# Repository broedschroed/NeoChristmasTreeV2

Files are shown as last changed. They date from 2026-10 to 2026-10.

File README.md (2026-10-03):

# NeoChristmasTree V2

An ESP32-powered Christmas tree ornament built from two interlocking,
fir-tree-shaped PCBs, lit by 66 individually addressable WS2812 LEDs and
controlled by an IR remote or a browser-based pattern editor.

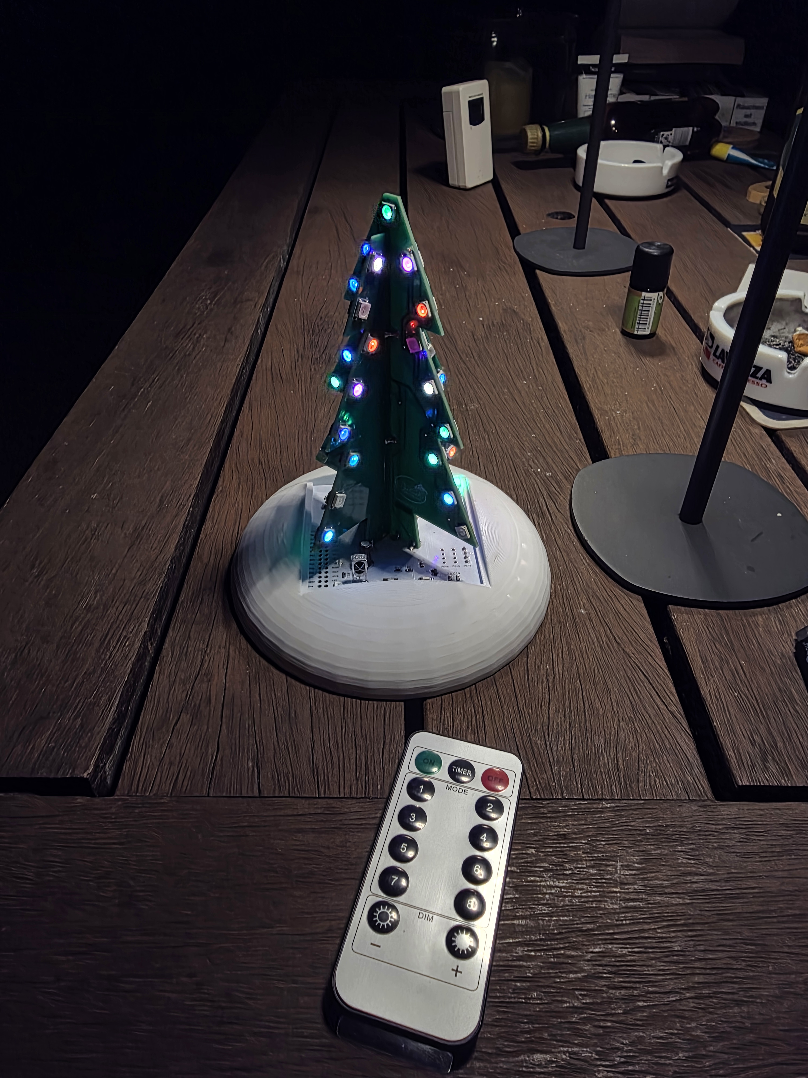
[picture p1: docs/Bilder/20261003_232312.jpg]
NeoChristmasTree lit up, with remote


## Highlights

- **66x WS2812 LEDs** across 4 wings (2 PCBs plugged together at a right
  angle, front and back of each), plus 2 tip LEDs at the very top.
- **IR remote control** — direct pattern selection, brightness, on/off, and
  a learnable sleep timer (30 minutes to 4 hours, set by repeatedly pressing
  the Timer button; the tree shows the corresponding "level" of its wings as
  live feedback).
- **Remote-learning mode** — any compatible IR remote's 13 buttons can be
  taught to the tree, with LED feedback on the tree itself during learning.
- **Browser-based pattern editor** — while powered via USB, the tree opens
  a local WiFi access point with a web UI (served from LittleFS) to create,
  edit, preview, and transfer lighting patterns between two trees.
- **Automatic brightness** — an onboard light sensor (LDR) adjusts LED
  brightness to the ambient light, capped by the brightness set via remote.
- **Proper power management** — on battery, switching off fully cuts power
  via a FET-driven double-click of the physical power button; on USB, the
  regulator stays active and only the LEDs go dark.

## Hardware

- ESP32 (NeoPixel data on pin 16)
- VS1838B IR receiver
- LDR for ambient-light sensing
- FET power switch to emulate a double-click power-off on battery
- Two interlocking fir-tree-shaped PCBs ("Tannenfluegellaengs" and
  "Tannenfluegelquer"), each carrying 32 of the 66 LEDs
- Main control board ("TannenbasisV4") carrying the ESP32, IR receiver, LDR
  and power management; KiCad sources for all three boards under
  `docs/Leiterplatten/`
- 3D-printed base housing; STL files under `docs/Gehäuse/`

## Repository layout

- `*.ino` / `*.h` — firmware (Arduino/ESP32 sketch)
- `data/www/` — the pattern editor web UI, uploaded to the ESP32's LittleFS
  filesystem (Arduino IDE "ESP32 Sketch Data Upload" or equivalent)
- `docs/manual/` — user manual (PDF)
- `docs/system/` — system documentation (PDF; describes an earlier hardware
  revision, kept for reference)
- `docs/Leiterplatten/` — KiCad sources, gerbers, schematic and front/back
  PCB renders for the control board and the two wing PCBs
- `docs/Gehäuse/` — STL files for the 3D-printed base housing
- `docs/Bilder/` — photos and a short clip of the finished tree

## Building

Open `NeoChristmasTreeV2.ino` in the Arduino IDE (or arduino-cli) with the
ESP32 core installed, plus the libraries IRremote, Adafruit NeoPixel,
ArduinoJson, and ESPAsyncWebServer. Flash the sketch, then upload the
contents of `data/` to the ESP32's LittleFS filesystem (e.g. via the "ESP32
Sketch Data Upload" tool) to make the pattern editor available.

Hold the mode/learn switch while powering on to enter IR remote-learning
mode.

## License

Released under the [MIT License](LICENSE).

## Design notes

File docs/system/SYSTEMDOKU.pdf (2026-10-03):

# NeoChristmasTree

## Systembeschreibung und Entwicklungsdokumentation

✦ ✦ ✦

Hardware: ESP32-S3-WROOM-1 · IP5306 · WS2812B Platine: TannenbasisV4 (KiCAD 10.0, 2-lagig) Software: Arduino / ESP-IDF · LittleFS · AsyncWebServer Gehäuse: 3D-Druck PLA (2-teiliger Einschub-Sockel)

────────────────────────────────────────────────────────────────────────────────

# 1 Projektübersicht

Der NeoChristmasTree ist ein ESP32-S3-basierter Weihnachtsbaum mit 66 adressierbaren WS2812B-LEDs, integriertem Akkubetrieb, Infrarot-Fernbedienung, WiFi-Webserver und automatischer Helligkeitsanpassung über einen Lichtsensor. Das Projekt richtet sich an Maker, die über grundlegende SMD-Löterfahrung verfügen, und zeigt einige unkonventionelle Lösungsansätze für typische Herausforderungen im Hobby-Bereich. Besondere Merkmale des Projekts:
- Integriertes Akkumanagement mit IP5306 (Laden und Boost in einem Chip) statt der üblichen zweiteiligen TP4056 + Boost-Converter-Lösung
- Eigens entwickeltes PCB-Footprint für den IP5306 mit extra großem GND-Thermal-Pad (3,65 × 8,55 mm) zum Löten ohne Heißluftstation
- USB-C-Stecker als Ladeeingang — Bestückung unter dem Kameramikroskop
- Webbasierter Pattern-Editor (LittleFS + AsyncWebServer) erreichbar über WiFi-Accesspoint
- Automatische LDR-Helligkeitsanpassung an das Umgebungslicht
- 2-teiliger 3D-Druck-Sockel mit Einschub-Mechanismus für die Platine

────────────────────────────────────────────────────────────────────────────────

# 2 Systemarchitektur

### 2.1 Blockdiagramm

Das folgende Diagramm zeigt den Energiepfad und die Datenflüsse des Systems:

┌──────────────┐ | USB-C (5 V) | ┌────────────────────────────────┐
│ LiPo-Akku | │◄────────────────►│ | IP5306 | │
│ | 1S / 3,7V │ | │ Laderegler + 5V-Boost-Wandler │
└──────────────┘ | │ Ladestandsanzeige (4 LEDs) | │
└──────────┬─────────────────────┘ │ 5 V Bus
┌────────────────────┼──────────────────────┐
│ | │ | │
┌──────▼──────┐ | ┌────────▼────────┐
┌────────▼───────┐
│ AMS1117-33 │ | │ 66× WS2812B | │ | │ BSS123 FET
│
│ 3,3V-Regler│ | │ LED-Strip | │ | │ Power-Switch
│
└──────┬──────┘ └─────────────────┘ └───────────────┘
│ 3,3 V

┌──────▼──────────────────────────────────────────────────┐
│ | ESP32-S3-WROOM-1
│
│
│
│ IO16 → WS2812-Daten IO38 ← IR-Empfänger VS1838B │
│ IO02 ← LDR (Analogein.) IO10 ← Taste mode/learn
│
│ IO04 ← Taste On/Off IO05 ← USB-Spannungsmessung │
│ IO15 → FET-Steuerung IO21 → Status-LED
│
│
│
│ WiFi-AP ──────────────► Webserver (192.168.4.1)
│
│ IR-Empfang ───────────► Pattern / Helligkeit / Power │

└──────────────────────────────────────────────────────────┘

### 2.2 Betriebsmodi

Modus | Stromversorgung | WiFi | Power-Off
Akkubetrieb | LiPo IP5306-Boost → → 5V | Aus (Stromsparen) | Vollständig (FET-Doppelklick)
USB-Betrieb | USB-C IP5306 → → 5V | AP aktiv | Nur LEDs aus, ESP32 aktiv

────────────────────────────────────────────────────────────────────────────────

# 3 Hardware-Beschreibung

### 3.1 Mikrocontroller — ESP32-S3-WROOM-1

Das Herzstück der Schaltung ist das ESP32-S3-WROOM-1-Modul von Espressif. Gegenüber dem älteren ESP32 bietet der S3 einen schnelleren Dual-Core-Xtensa-LX7-Prozessor (240 MHz), mehr SRAM (512 KB intern) sowie USB-OTG-Unterstützung. Für dieses Projekt entscheidend ist die reichhaltige Peripherie: ausreichend GPIOs für LEDs, IR, LDR und Taster sowie das integrierte WiFi für den Webserver.
Parameter | Wert
Prozessor | Dual-Core Xtensa LX7, 240 MHz
Flash | 4 MB (im Modul, genutzt für LittleFS-Patterns)
RAM | 512 KB intern + 8 MB PSRAM (im Modul)
WiFi | 802.11 b/g/n, 2,4 GHz
Betriebsspannung | 3,3 V
Versorgung | AMS1117-3.3 (aus 5V-Bus des IP5306)

Das Modul enthält bereits alle notwendigen Beschaltungen (Quarz, Filter, Antenne). Auf der Platine sind lediglich die Abblockkondensatoren und die GPIO-Beschaltung nötig.

### 3.2 Akkumanagement — IP5306 vs. TP4056 + Boost

Die Wahl des Akkumanagement-ICs ist eine der zentralen Designentscheidungen dieses Projekts. In vielen Maker-Projekten wird die Kombination aus TP4056 (Ladecontroller) und einem separaten Boost-Converter (z. B. MT3608 oder SY7208) verwendet. Diese Lösung hat einige Nachteile, die der IP5306 in einem einzigen Chip behebt.

Warum nicht TP4056 + Boost? Die klassische Kombination benötigt zwei ICs mit je eigenem Induktor, eigener Beschaltung und eigenem Wirkungsgrad-Verlust. Der Ladestrom des TP4056 ist auf 1A begrenzt. Die Gesamteffizienz leidet durch die zwei Wandlerstufen — besonders bei niedrigem Akkustand.

Eigenschaft | TP4056 + MT3608 | IP5306 (dieses Projekt)
Integration | 2 ICs + 2 Induktoren | 1 IC + 1 Induktor
Max. Ladestrom | 1,0 A | 2,1 A (einstellbar)
Boost-Ausgangsstrom | bis ~2 A (MT3608) | bis 2,4 A
Boost-Effizienz | ~80–87 % | ~88–93 %
Power-Button-Logik | Extern nötig | Integriert (Doppelklick-Erkennung)
Ladestandsanzeige | Extern (keine oder 1 LED) | 4 LEDs direkt angesteuert
Platzbedarf | Groß (2 Footprints) | SOP-8 (8 × 5 mm)
Preis (ca.) | ~1,50 € (2 ICs) | ~0,80 € (1 IC)

Der IP5306 enthält einen synchronen Boost-Wandler mit integrierter Schottky-Diode und einem eigenen Laderegler. Besonders wertvoll für dieses Projekt: Der Chip erkennt Einfach- und Doppelklick auf den Power-Button in Hardware — genau die Logik, die für das Abschalten im Akkubetrieb benötigt wird.

Power-Button-Trick: Im Akkubetrieb schaltet ein Doppelklick auf den Power-Button den IP5306 vollständig ab. Der ESP32 simuliert diesen Doppelklick über einen BSS123-FET auf den Power-Pin
— so ist ein vollständiges Software-Power-Off möglich, ohne dass der Nutzer den Taster zweimal drücken muss.

Die vier Ladestand-LEDs (D1–D4, bestückt als SMD-LEDs 1210) zeigen in 25-%-Schritten den Akkustand an. Der IP5306 treibt diese LEDs direkt ohne externe Logik.

### 3.3 3,3V-Versorgung — AMS1117-3.3

Aus dem 5V-Bus des IP5306 erzeugt ein AMS1117-3.3 im SOT-223-Gehäuse die 3,3V für den ESP32-S3. Der AMS1117 ist ein LDO-Regler (Low-Dropout) mit bis zu 800 mA Ausgangsstrom — ausreichend für den ESP32 inklusive WiFi-Betrieb. Die Dropout-Spannung von ca. 1,2V ist bei einem 5V-Eingang unkritisch.
Parallel zum AMS1117 liegen Abblockkondensatoren (100nF keramisch + 100µF elektrolytisch) um Lastsprünge durch WiFi-Bursts und LED-Datenübertragung zu glätten.

### 3.4 Ladeeingang — USB-C-Stecker (Lötbesonderheit!)

Als Ladeeingang dient ein USB-C-Plug in einem eigens erstellten KiCAD-Footprint. USB-C bietet gegenüber Micro-USB den Vorteil der Steckerrichtungsfreiheit und höherer mechanischer Belastbarkeit — relevant für ein Gerät, das jede Weihnachtssaison aus der Schublade geholt und angeschlossen wird.

Löthinweis — Kameramikroskop empfohlen: Der USB-C-Connector hat Signalpins (CC1/CC2,
D+/D ) mit einer Breite von nur − | 0,3 mm und einem Pitch von 0,5 mm. Die GND- und VBUS-Pads
messen 0,6 mm. Ein Kameramikroskop (oder zumindest eine starke Lupe mit guter Beleuchtung) ist beim Bestücken und Verlöten dringend empfohlen, um Brücken zwischen den Pins zu
erkennen und zu beseitigen. Flussmittel-Gel und eine feine Lötspitze (max. 0,3 mm) sind Pflicht.

Mechanisch hält der Connector über vier Through-Hole-Lötösen (ovale Pads 1,0 × 1,8 mm und 1,0 × 2,1 mm), die auch von Hand gut verlötbar sind und die nötige Zugentlastung bieten.

### 3.5 Infrarot-Empfänger — VS1838B

Der VS1838B (Footprint: TSDP341xx) ist ein kompakter 38-kHz-IR-Empfänger im 3-Pin-Gehäuse. Er demoduliert das Trägersignal und liefert direkt das NEC-Protokoll-Signal an GPIO38 des ESP32. Die Library IRremote übernimmt die Dekodierung.
Besonderheit im Code: `strip.show()` wird nur aufgerufen, wenn `IrReceiver.isIdle()` true ist, um elektromagnetische Interferenzen zwischen WS2812-Datenleitung und IR-Empfänger zu vermeiden.

### 3.6 Umgebungslicht — LDR-Spannungsteiler

An GPIO2 liegt ein Spannungsteiler aus LDR (gegen VCC) und 100 kΩ (gegen GND). Bei
hellem Umgebungslicht sinkt der LDR-Widerstand höhere Spannung an GPIO2 → | →
höherer ADC-Wert hellere LEDs. Bei Dunkelheit kehrt sich das um. →
Der ESP32 liest den ADC-Wert alle 500 ms (konfigurierbar über `AUTO_BR_INTERVAL`) und mappt ihn linear auf den Helligkeitsbereich `[AUTO_BR_MIN, gBrightness]`. Dabei wirkt der per Fernbedienung eingestellte Wert `gBrightness` als Obergrenze — die automatische Helligkeit kann nie höher gehen als die manuelle Einstellung.
#define LDR_DARK | 200 | // ADC-Wert bei Dunkelheit → kalibrieren!

#define LDR_BRIGHT | 3500 | // ADC-Wert bei hellem Licht → kalibrieren!

#define AUTO_BR_MIN | | 3 // LED-Helligkeit bei Dunkelheit

#define AUTO_BR_MAX | 255 // LED-Helligkeit bei vollem Licht

#define AUTO_BR_INTERVAL | 500 // Messintervall in ms

### 3.7 Power-Management — BSS123 N-Kanal-FET

Ein BSS123 (SOT-23, N-Kanal-MOSFET, 170 mA, 100 V) verbindet GPIO15 des ESP32 mit dem Power-Button-Pin des IP5306. Durch gezielte Pulse auf GPIO15 simuliert der ESP32 den für den IP5306 erforderlichen Doppelklick zum Abschalten. Im USB-Betrieb wird dieser Pfad nicht genutzt (IP5306 kann über USB nicht vollständig abschalten).

────────────────────────────────────────────────────────────────────────────────

# 4 Platinen-Design (TannenbasisV4)

### 4.1 Übersicht

Parameter | Wert
Design-Tool | KiCAD 10.0
Lagen | 2 (F.Cu, B.Cu)
Abmessungen | ca. 80 × 60 mm (Schätzwert aus Bauteilkoordinaten)
Oberfläche | HASL oder ENIG empfohlen
Bestückung | Überwiegend SMD 0805, wenige THT-Bauteile

### 4.2 IP5306 — Das besondere Lötpad

Der IP5306 im SOP-8-Gehäuse hat acht Standard-Gullwing-Pads (2,85 × 0,7 mm) und ein thermisches Exposed-Pad (Pad 9, GND) auf der Unterseite. Dieses Thermal-Pad ist für die Wärmeableitung essenziell — und genau hier liegt die konstruktive Besonderheit dieses Designs.

Lötpad-Größe im Vergleich: Das Thermal-Pad des IP5306 ist im Standard-Datenblatt mit ca. 3,3 × 3,3 mm angegeben. Im Footprint dieses Projekts wurde ein kombiniertes Pad von 3,65 × 8,55 mm definiert (inklusive Lötbrücken-Flächen). Zusätzlich gibt es drei Thermal-Via-Löcher ( 0,5 ∅ mm) auf beiden Seiten des Chips, die das Pad für einen Standardlötkolben zugänglich machen.

Das Ergebnis: Wer keinen Heißluftlöter besitzt, kann den IP5306 mit einem 100-Watt-Lötkolben und ausreichend Flussmittel von der Seite über die Thermal-Vias verlöten. Die Vias leiten Wärme und Lot unter den Chip.

### 4.3 Schaltplan und Layout

Die folgenden Dokumente liegen dem Projekt bei:
- `docs/schematic.pdf` — vollständiger Schaltplan (exportiert aus KiCAD)
- `docs/pcb_front.pdf` — PCB-Vorderseite (F.Cu + Silkscreen + Outline)
- `docs/pcb_back.pdf` — PCB-Rückseite (B.Cu + Silkscreen + Outline)
- `TannenbasisV4-produce/` — fertige Gerber-Dateien für die Platinenfertigung Die Gerber-Dateien sind direkt bei Standard-PCB-Fertigern (z. B. JLCPCB, PCBWay) bestellbar.

────────────────────────────────────────────────────────────────────────────────

# 5 3D-Druck-Sockel

### 5.1 Konzept

Der Sockel ist als zweiteiliger Einschub konstruiert. Die Platine wird in den Hauptkörper eingeschoben und durch ein Endstück gesichert — keine Schrauben, kein Kleber. Das ermöglicht einfachen Zugang zur Platine für Wartung oder Umprogrammierung.

Datei | Beschreibung
`XmasTree-Base3-2-main.stl` | Hauptkörper mit Einschubführung für die Platine
`XmasTree-Base3-2-end.stl` | Abschlusskappe, sichert die Platine im Sockel

### 5.2 Druckempfehlungen

- Material: PLA (ausreichend für Innenbereich)
- Schichthöhe: 0,2 mm (Standardqualität)
- Infill: 20 % (Gyroid oder Grid)
- Supports: nicht erforderlich (Teile sind support-frei konstruiert)
- Perimeter: 3 Wände für ausreichende Stabilität der Einschubführung

────────────────────────────────────────────────────────────────────────────────

# 6 Software-Architektur

### 6.1 Übersicht der Module

Der Quellcode ist in mehrere `.ino`-Dateien aufgeteilt, die die Arduino-IDE gemeinsam kompiliert:
Datei | Funktion
`NeoChristmasTreeV2.ino` | Hauptdatei: Setup, Loop, Auto-Brightness, Power-Off-Logik
`pattering.ino` | Pattern-Renderer: liest aus PatternEngine, setzt LEDs
`IRhandling.ino` | IR-Empfang, IR-Lernmodus (12 Codes × 3-fache Bestätigung)
`filesystem.ino` | LittleFS: Pattern-Index laden, Pattern-JSON lesen/schreiben
`webserver.ino` | WiFi-AP + AsyncWebServer + REST-API für den Pattern-Editor
`myPrefHandling.ino` | NVS-Preferences: IR-Codes, Pattern-ID,

| Helligkeit persistent
`serialprintf.ino` | sprintf-Wrapper für komfortables Serial-Debugging
`PatternEngine.h` | Datenstruktur für geladene Patterns (Frames, Farben, Timing)
`AllPattern.h` | Definitionen eingebauter Fallback-Patterns
`IRcodes.h` | Default-IR-Codes (Golden Power Ningbo Fernbedienung)

### 6.2 Pattern-System (LittleFS + JSON)

Lichtmuster werden als JSON-Dateien im LittleFS-Dateisystem des ESP32-Flash gespeichert. Ein zentraler Index (`/patterns/_index.json`) listet alle verfügbaren Patterns mit ID und Anzeigename.

// Verzeichnisstruktur im Flash:
/patterns/
_index.json | ← Liste aller Patterns
[{"id":"rainbow","name":"Regenbogen"}, ...]
rainbow.json | ← Pattern-Daten (Frames, Farben, Timing)
snowfall.json
/www/
index.html | ← Pattern-Editor (Single-Page-App)

Das aktive Pattern wird über eine String-ID (z. B. `"rainbow"`) referenziert — nicht über einen Integer-Index. Das macht Patterns unabhängig von ihrer Reihenfolge und ermöglicht das Hinzufügen/Entfernen ohne Neukompilierung der Firmware.

### 6.3 WiFi-Accesspoint und Web-Editor

Im USB-Betrieb öffnet der ESP32 automatisch einen WiFi-Accesspoint (`SSID: ChristmasTree`, kein Passwort). Der AsyncWebServer liefert die Single-Page-App (HTML/JavaScript) und stellt folgende REST-Endpunkte bereit:
Endpunkt | Methode | Funktion
`/` | GET | Liefert index.html (Pattern-Editor-UI)

`/api/patterns` | GET | Gibt _index.json zurück (Patternliste)
`/api/pattern?id=X` | GET | Gibt Pattern-JSON für ID X zurück
`/api/pattern` | POST | Speichert Pattern-JSON (id im Body)
`/api/activate` | POST | Aktiviert Pattern direkt (ohne Speichern)
`/api/brightness` | POST | Setzt Helligkeit live

### 6.4 IR-Fernbedienung

Der IR-Empfänger wird über die IRremote-Library ausgelesen. Zwölf IR-Codes sind konfigurierbar (Patterns 1–8, OFF, ON, Dunkler, Heller) und werden im NVS-Flash gespeichert. Der Lernmodus (Taste `mode/learn` beim Einschalten gehalten) erfasst neue Codes mit dreifacher Bestätigung, um instabile China-Fernbedienungen zu tolerieren.

### 6.5 Automatische Helligkeit (LDR)

Die Auto-Brightness-Funktion liest den LDR-Wert alle `AUTO_BR_INTERVAL` Millisekunden und mappt ihn über `constrain()` und `map()` auf den Helligkeitsbereich:

void updateAutoBrightness() {
if (millis() - gLastLdrCheck < AUTO_BR_INTERVAL) return; gLastLdrCheck = millis();
int raw = analogRead(ROOMLIGHT);
int clamped = constrain(raw, LDR_DARK, LDR_BRIGHT);
int autoBr = map(clamped, LDR_DARK, LDR_BRIGHT, AUTO_BR_MIN, AUTO_BR_MAX);
autoBr | = constrain(autoBr, AUTO_BR_MIN, gBrightness); // IR-Wert als
Deckel
strip.setBrightness(autoBr);
}

### 6.6 Power-Management im Code

Die Firmware unterscheidet USB- und Akkubetrieb anhand des analogen Spannungswerts an `USB5VSENSE` (GPIO5). Liegt dieser unter 1000 (ADC-Rohwert), wird Akkubetrieb angenommen:
- USB: WiFi-AP starten, echter Power-Off nicht möglich `"offpattern"` anzeigen →
- Akku: WiFi aus, bei Ausschalt-Befehl FET-Doppelklick ausführen (`powerOff()`)

────────────────────────────────────────────────────────────────────────────────

# 7 Stückliste (BOM)

Automatisch extrahiert aus `TannenbasisV4.kicad_sch` (KiCAD 10.0). Alle SMD-Widerstände und -Kondensatoren sind im Format 0805 ausgeführt (handlöttauglich). Elektrolytkondensatoren sind bedrahtet (Radial).
Stk. | Referenz(en) | Wert / Typ | Footprint
3 | C1, C2, C13 | 10µF | C_0805_2012Metric
1 | C14 | 100n | C_0805_2012Metric
2 | C3, C8 | 100nF | C_0805_2012Metric
2 | C4, C12 | 100µF | CP_Radial_D6.3mm_ P2.50mm
6 | C5, C6, C7, C9, C10, C11 | 22µF | C_1210_3225Metric_ Pad1.33x2.70mm
1 | D1 | 25% | LED_1210_3225Metr ic_Pad1.42x2.65mm
1 | D2 | 50% | LED_1210_3225Metr ic_Pad1.42x2.65mm
1 | D3 | 75% | LED_1210_3225Metr ic_Pad1.42x2.65mm
1 | D4 | 100% | LED_1210_3225Metr ic_Pad1.42x2.65mm
1 | D6 | LED | LED_1210_3225Metr ic_Pad1.42x2.65mm
1 | J1 | Battery | PinHeader_1x02_P2. 54mm_Vertical
2 | J10, J11 | LED2in | solderconnect-1
1 | J12 | USB_B_Micro | USB_Micro-B_Pins
2 | J13, J14 | mount | solderconnect-1

1 | J15 | I2Cb | PinHeader_1x04_P2. 54mm_Vertical
1 | J16 | I2Ca | PinHeader_1x04_P2. 54mm_Vertical
1 | J18 | LDR | PinHeader_1x02_P2. 54mm_Vertical
1 | J19 | Developer-IO | PinHeader_2x14_P2. 54mm_Vertical
2 | J2, J3 | LEDvdd | solderconnect-1
1 | J20 | I2Cc | PinHeader_1x04_P2. 54mm_Vertical
2 | J4, J5 | LEDvss | solderconnect-1
2 | J6, J7 | LEDdata | solderconnect-1
2 | J8, J9 | LED1out | solderconnect-1
1 | L1 | 1µH | MyPowerCoil
1 | P2 | USB-C-Plug-My | MyUSB-C
1 | Q1 | BSS123 | SOT-23
4 | R1, R2, R7, R8 | 1Ω | R_0805_2012Metric
3 | R10, R12, R14 | 100Ω | R_0805_2012Metric
1 | R11 | 220Ω | R_0805_2012Metric
1 | R17 | 1k | R_0805_2012Metric
2 | R3, R4 | 5k1 | R_0805_2012Metric
3 | R5, R16, R19 | 100k | R_0805_2012Metric
5 | R6, R9, R13, R15, R18 | 10k | R_0805_2012Metric
1 | SW1 | On/Off | SW_DIP_SPSTx01_Sli de_6.7x4.1mm_W8.6 1mm_P2.54mm_Low Profile
1 | SW2 | Reset | SW_DIP_SPSTx01_Sli de_6.7x4.1mm_W8.6 1mm_P2.54mm_Low Profile
1 | SW3 | mode/learn | SW_DIP_SPSTx01_Sli de_6.7x4.1mm_W8.6 1mm_P2.54mm_Low

| | | Profile
1 | SW4 | Boot/Flash | SW_DIP_SPSTx01_Sli de_6.7x4.1mm_W8.6 1mm_P2.54mm_Low Profile
1 | U1 | IP5306 | IP5306
1 | U2 | AMS1117-3.3 | SOT-223-3_TabPin2
1 | U3 | USBLC6-2SC6 | SOT-23-6
1 | U4 | VS1838B | Vishay_MOLD-3Pin
1 | U5 | ESP32-S3-WROOM-1 | ESP32-S3-WROOM-1

Gesamt: 69 Bauteile in 42 verschiedenen Typen.

────────────────────────────────────────────────────────────────────────────────

# 8 Inbetriebnahme

### 8.1 Firmware flashen

### 1. Arduino-IDE installieren und das ESP32-Boardpaket (Espressif, Version 2.0) ≥

einrichten.
2. Folgende Libraries installieren: IRremote, Adafruit NeoPixel, ESPAsyncWebServer, ArduinoJson, LittleFS.
3. Den ESP32 über den USB-Micro-B-Connector (J12) mit dem Computer verbinden.
4. Das Sketch `NeoChristmasTreeV2.ino` öffnen und auf den ESP32 hochladen.
5. Anschließend die LittleFS-Daten hochladen (Arduino-IDE Werkzeuge ESP32 → | →
LittleFS Data Upload). Enthält Pattern-JSON und den Web-Editor.

### 8.2 LDR kalibrieren

Die Rohwerte des LDR sind je nach verbautem Exemplar und Lichtbedingungen unterschiedlich. Kalibrierung:
1. Baum einschalten und Serial Monitor (115200 Baud) öffnen.
2. Den Baum in vollständiger Dunkelheit aufstellen `ROOMLIGHT=`-Wert notieren → | →
als `LDR_DARK` eintragen.

3. Den Baum bei normaler Raumbeleuchtung aufstellen Wert notieren als → | →
`LDR_BRIGHT` eintragen.
4. Firmware neu flashen.

### 8.3 IR-Fernbedienung anlernen

Falls eine andere als die mitgelieferte Fernbedienung (Golden Power Ningbo) verwendet werden soll: Taste `mode/learn` beim Einschalten gedrückt halten Lernmodus. 12 Tasten → nacheinander dreimal drücken. Details: siehe Bedienungsanleitung.

────────────────────────────────────────────────────────────────────────────────

NeoChristmasTree · TannenbasisV4 · broed · 2025

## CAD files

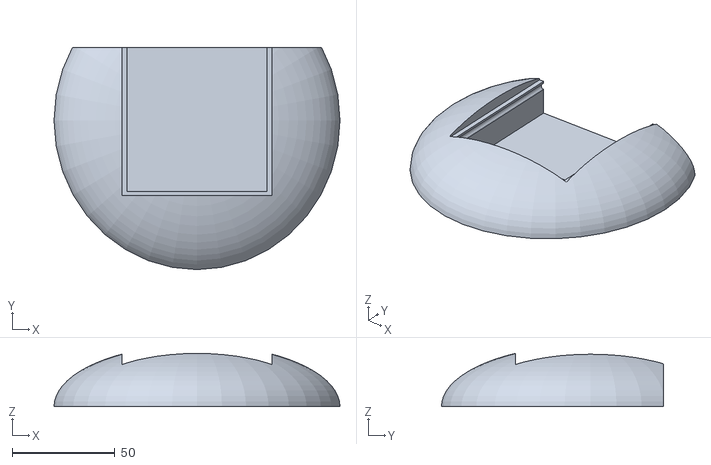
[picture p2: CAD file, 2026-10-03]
docs/Gehäuse/XmasTree-Base3-2-main.stl
139.0 x 108.0 x 25.9

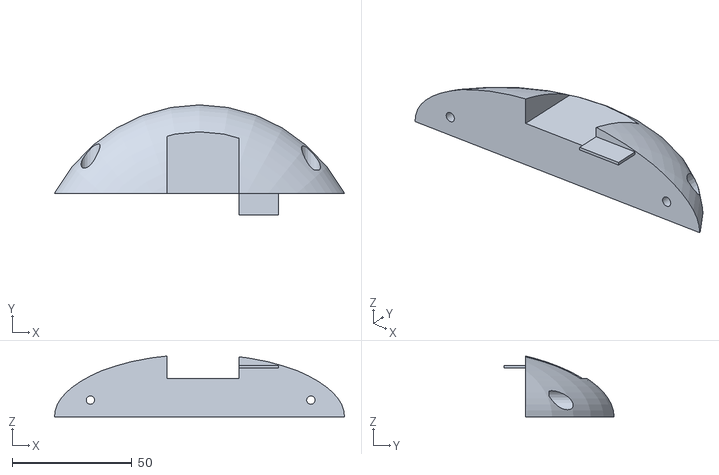
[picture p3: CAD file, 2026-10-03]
docs/Gehäuse/XmasTree-Base3-2-end.stl
121.0 x 46.0 x 25.4

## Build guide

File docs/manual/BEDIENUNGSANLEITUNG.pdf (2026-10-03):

# 🎄 NeoChristmasTree

## Bedienungsanleitung

✦ ✦ ✦

Dieser Weihnachtsbaum leuchtet in vielen verschiedenen Mustern und passt seine Helligkeit sogar selbst an das Raumlicht an. Diese Anleitung führt dich Schritt für Schritt vom Einschalten bis zur Anpassung der Lichtmuster — ganz ohne Vorkenntnisse.

────────────────────────────────────────────────────────────────────────

### 1 Die Tasten am Baum

Am Baum selbst gibt es zwei Tasten: die Taste On/Off zum Ein- und Ausschalten und die Taste mode/learn zum Wechseln der Lichtmuster. Außerdem passt der Baum seine Helligkeit automatisch dem Raumlicht an.
Einschalten
Die Taste On/Off einmal kurz drücken — der Baum startet und zeigt das zuletzt verwendete Muster.
Ausschalten
Die Taste On/Off erneut kurz drücken — der Baum geht aus.

Gut zu wissen: Das zuletzt verwendete Muster und die Helligkeit werden automatisch gespeichert. Beim nächsten Einschalten macht der Baum genau dort weiter, wo er aufgehört hat.

Muster wechseln
Die Taste mode/learn einmal kurz drücken — der Baum wechselt zum nächsten Lichtmuster. Einfach so oft drücken, bis das gewünschte Muster erscheint. Nach dem letzten Muster beginnt die Liste wieder von vorne.
Automatische Helligkeit
Im Baum ist ein kleiner Lichtsensor eingebaut. Er misst ständig, wie hell es im Raum ist, und passt die LED-Helligkeit automatisch an:

- Tagsüber oder bei eingeschaltetem Licht leuchtet der Baum heller.
- Abends oder bei gedimmtem Licht leuchtet der Baum sanfter.
Das passiert ganz von selbst — es ist nichts einzustellen. Die per Fernbedienung eingestellte Helligkeit wirkt dabei als Obergrenze: Heller als dieser Wert wird der Baum nie, auch wenn der Raum sehr hell ist.

────────────────────────────────────────────────────────────────────────

### 2 Die Fernbedienung

Mit der Fernbedienung lässt sich der Baum bequem aus dem Sessel steuern. Einfach auf den Baum richten und die gewünschte Taste drücken.
Muster direkt auswählen
Die Zifferntasten 1 bis 8 rufen die gespeicherten Lichtmuster direkt auf:
Taste | Muster
1 Zufällig wechselnde Farben 2 Klassisch-festliches Muster 3 Blinkende Lichter
4 Farben laufen den Baum hinauf 5 Farbige Linien
6 Farbige Seiten
7 Schneeeffekt in Weiß
8 Weißes Blinken

Tipp: Wenn eigene Muster über den WLAN-Editor gespeichert wurden (siehe Kapitel 4), können diese ebenfalls per Fernbedienung aufgerufen werden — die Tasten 1–8 zeigen dann die ersten acht Muster in der gespeicherten Liste.

Helligkeit einstellen
Taste | Funktion
dark | Baum etwas dunkler schalten
light | Baum etwas heller schalten

Einfach mehrfach drücken, bis die gewünschte Helligkeit erreicht ist. Diese Einstellung wird gespeichert und gilt als neuer Helligkeits-Höchstwert für die automatische Anpassung (siehe Kapitel 1).
Ein- und Ausschalten
Taste | Funktion
ON | Baum einschalten (zeigt das zuletzt aktive Muster)
OFF | Baum ausschalten

Was genau beim Ausschalten passiert, hängt davon ab, ob der Baum per USB oder per Akku betrieben wird — dazu mehr im nächsten Kapitel.

────────────────────────────────────────────────────────────────────────
Timer — automatisches Ausschalten
Die Taste Timer stellt eine automatische Abschaltzeit ein — praktisch, wenn der Baum abends von selbst ausgehen soll:

### 1. Timer einmal drücken: Die untersten LEDs des Baums leuchten kurz gold auf —

der Baum schaltet sich in 30 Minuten automatisch aus.

### 2. Timer erneut drücken, solange die LEDs noch leuchten: Eine weitere Ebene

leuchtet mit auf, die Abschaltzeit erhöht sich um weitere 30 Minuten.

### 3. So oft weiterdrücken, bis die gewünschte Zeit erreicht ist — jede Ebene entspricht

30 Minuten, bis hin zu 4 Stunden, wenn der ganze Baum leuchtet.

### 4. Ist die höchste Stufe (4 Stunden, ganzer Baum) erreicht, schaltet ein weiterer

Druck auf Timer die automatische Abschaltung wieder komplett aus — der Baum läuft sofort normal weiter.
Nach jedem Tastendruck läuft nach der kurzen Anzeige das zuvor aktive Lichtmuster ganz normal weiter; der Timer zählt im Hintergrund mit. Wird der Baum vor Ablauf der Zeit manuell aus- oder eingeschaltet (Taste On/Off am Baum, ON/OFF auf der Fernbedienung), wird der Timer automatisch verworfen. Beim Ablauf der Zeit schaltet sich der Baum genauso ab wie über die Taste OFF — im Akkubetrieb also vollständig, im USB-Betrieb gehen nur die LEDs aus (siehe nächstes Kapitel).

### 3 USB oder Akku — was ist der Unterschied?

Der Baum kann auf zwei Arten mit Strom versorgt werden: über ein USB-Kabel (z. B. an einem Netzteil oder Computer) oder über einen eingebauten Akku. Je nach Stromversorgung verhält er sich beim Ausschalten etwas anders.
Akkubetrieb
Im Akkubetrieb schaltet sich der Baum beim Ausschalten vollständig ab — auch die Elektronik im Inneren geht schlafen. Das spart Strom und schont den Akku.
- Einschalten: Taste On/Off am Baum einmal kurz drücken.
- Ausschalten: Taste On/Off am Baum einmal kurz drücken oder Taste OFF auf der Fernbedienung.
- Nach dem Ausschalten ist der Baum komplett stromlos. Er lässt sich nur wieder mit der Taste On/Off starten — die Fernbedienung funktioniert erst wieder, nachdem der Baum eingeschaltet wurde.

Hinweis: Wenn der Akku leer ist und der Baum gerade ausgeschaltet ist, schaltet er sich von selbst ab — damit sich der Akku nicht tiefentlädt.

USB-Betrieb
Über USB kann die Elektronik im Inneren nicht vollständig abgeschaltet werden — das ist technisch bedingt. Deshalb verhält sich der Baum hier etwas anders:
- Einschalten: USB-Kabel einstecken — der Baum startet automatisch.
- Ausschalten: Taste On/Off am Baum drücken oder Taste OFF auf der Fernbedienung → die LEDs gehen aus, aber die Elektronik bleibt aktiv.
- Wieder einschalten: Taste On/Off am Baum erneut drücken oder Taste ON auf der Fernbedienung.

Akku laden: Während der Baum per USB betrieben wird, lädt gleichzeitig der eingebaute Akku. Es empfiehlt sich daher, den Baum gelegentlich ans USB-Kabel zu hängen — besonders nach längerem Akkubetrieb.

Ein weiterer Vorteil des USB-Betriebs: Der Baum öffnet automatisch ein WLAN-Netzwerk, über das sich Lichtmuster am Tablet oder Notebook anpassen lassen (siehe nächstes Kapitel).

────────────────────────────────────────────────────────────────────────

### 4 Lichtmuster anpassen — der WLAN-Editor

Wenn der Baum per USB betrieben wird, öffnet er automatisch ein eigenes WLAN-Netzwerk. Darüber lassen sich die vorhandenen Lichtmuster am Tablet oder Notebook anpassen, speichern und sogar zwischen zwei Bäumen übertragen.

Voraussetzung: Der Baum muss per USB eingeschaltet sein. Im Akkubetrieb ist der WLAN-Editor nicht verfügbar.

Schritt 1 — Mit dem Baum verbinden
1. Am Tablet oder Notebook die WLAN-Einstellungen öffnen.

### 2. Das Netzwerk „ChristmasTree" auswählen und verbinden. Es wird kein Passwort

benötigt.
3. Einen Browser öffnen (z. B. Chrome, Firefox oder Safari).
4. In die Adresszeile oben 192.168.4.1 eintippen und die Eingabetaste drücken.
5. Der Muster-Editor erscheint im Browser.

Tipp: Falls nach dem Verbinden eine Meldung erscheint, dass „kein Internet verfügbar" ist — das ist normal und gewollt. Der Baum ist kein Internet-Router, sondern nur ein kleines lokales Netzwerk. Den Hinweis einfach wegklicken und den Browser öffnen.

Schritt 2 — Ein vorhandenes Muster verändern
Der einfachste Einstieg: Ein bestehendes Muster als Ausgangspunkt nehmen und anpassen.

### 1. Oben links in der Muster-Auswahlliste ein Muster auswählen — es wird sofort im

Editor angezeigt.

### 2. Im LED-Raster (Mitte) zeigt sich der Baum in einer vereinfachten Draufsicht. Jedes

Kästchen ist eine LED.
3. Rechts die gewünschte Farbe aus der Palette auswählen.
4. Im LED-Raster auf eine LED klicken — sie leuchtet in der gewählten Farbe.
5. Wenn das Muster gefällt: „ Aktivieren" ▶ | klicken, um es sofort am Baum zu sehen.
6. „ Speichern" ↑ | klicken, um das Muster dauerhaft zu sichern.

Überblick über alle Schaltflächen
Schaltfläche | Was sie macht
Muster-Auswahlliste | Gespeichertes Muster auswählen und im Editor laden
- Aktivieren | Das aktuell angezeigte Muster sofort am Baum anzeigen
↺ Original | Muster auf die Werkseinstellung zurücksetzen
Helligkeitsregler | LED-Helligkeit am Baum live verändern
↓ Import JSON | Ein Muster von einem anderen Baum einspielen
↑ Export JSON | Aktuelles Muster als Text kopieren, um es zu teilen
- Vorschau | Muster im Browser animiert abspielen (ohne den Baum)
↑ Speichern | Muster dauerhaft auf dem Baum speichern
PCB1 PCB2 → | Linke Baumhälfte spiegelgleich auf die rechte übertragen

Muster zwischen zwei Bäumen übertragen

Vom ersten Baum exportieren:
1. Das gewünschte Muster in der Auswahlliste auswählen.
2. „ Export JSON" ↑ | klicken — ein Textfeld mit dem Muster-Code öffnet sich.
3. „Kopieren" klicken.
Auf dem zweiten Baum einspielen:
1. Mit dem zweiten Baum verbinden (WLAN „ChristmasTree", Adresse 192.168.4.1).
2. „ Import JSON" ↓ | klicken — ein Eingabefenster öffnet sich.
3. Den kopierten Text einfügen (Strg+V).
4. „Importieren" klicken — das Muster erscheint im Editor.
5. „ Speichern" ↑ | klicken, um es dauerhaft zu sichern.

────────────────────────────────────────────────────────────────────────

### 5 Eine andere Fernbedienung anlernen

Der Baum merkt sich die Tasten einer bestimmten Fernbedienung. Soll eine andere Fernbedienung verwendet werden, müssen deren Tasten einmalig angelernt werden. Das dauert nur wenige Minuten.

Achtung: Dieser Vorgang löscht die bisherigen Fernbedienungstasten. Danach funktioniert nur noch die neu angelernte Fernbedienung.

Vorbereitung
- Den Baum ausschalten.
- Die neue Fernbedienung bereithalten.
- Die Taste mode/learn am Baum suchen — sie wird gleich beim Einschalten gedrückt. Lernmodus starten
1. Die Taste mode/learn am Baum gedrückt halten.
2. Gleichzeitig den Baum mit der Taste On/Off einschalten.

### 3. Die Taste mode/learn halten, bis die oberste LED rot leuchtet — das zeigt an, dass

der Baum bereit zum Lernen ist.
4. Taste mode/learn loslassen.
Tasten nacheinander anlernen
Der Baum erwartet nun genau 13 Tasten in einer festgelegten Reihenfolge. Für jede Taste gilt:
- Die gewünschte Taste auf der Fernbedienung dreimal hintereinander drücken — mit einer kurzen Pause zwischen den Drücken.
- Der Baum bestätigt jeden erfolgreich angelernten Code: Die Baumspitze blinkt zweimal auf.

Die Reihenfolge der 13 Tasten:
Schritt | Funktion
1 | Muster 1
2 | Muster 2
3 | Muster 3
4 | Muster 4
5 | Muster 5
6 | Muster 6
7 | Muster 7
8 | Muster 8
9 | Ausschalten (OFF)
10 | Einschalten (ON)
11 | Dunkler
12 | Heller
13 | Timer

Fortschrittsanzeige: Während des Lernens leuchtet auf allen vier Flügeln des Baums jeweils die Ebene 4 bis 6 in Farben auf und zeigt so an, wie weit der Lernvorgang fortgeschritten ist:
Farbe | Bedeutung
Grün | Tasten 1–3 gelernt
Cyan (Türkis) | Tasten 4–6 gelernt
Gelb | Tasten 7–9 gelernt
Magenta (Pink) | Tasten 10–12 gelernt
Weiß | Taste 13 (Timer) gelernt

Sobald alle 13 Tasten angelernt sind, speichert der Baum die Codes automatisch und startet normal. Die neue Fernbedienung ist sofort einsatzbereit.

Falls eine Taste nicht akzeptiert wird: Einfach dieselbe Taste erneut dreimal drücken. Manche Fernbedienungen senden beim ersten Druck einen anderen Code als bei den folgenden — der Baum verlangt daher dreimal denselben Code zur Sicherheit.

────────────────────────────────────────────────────────────────────────
🎄 | 🎄 NeoChristmasTree — viel Freude mit deinem leuchtenden Baum!

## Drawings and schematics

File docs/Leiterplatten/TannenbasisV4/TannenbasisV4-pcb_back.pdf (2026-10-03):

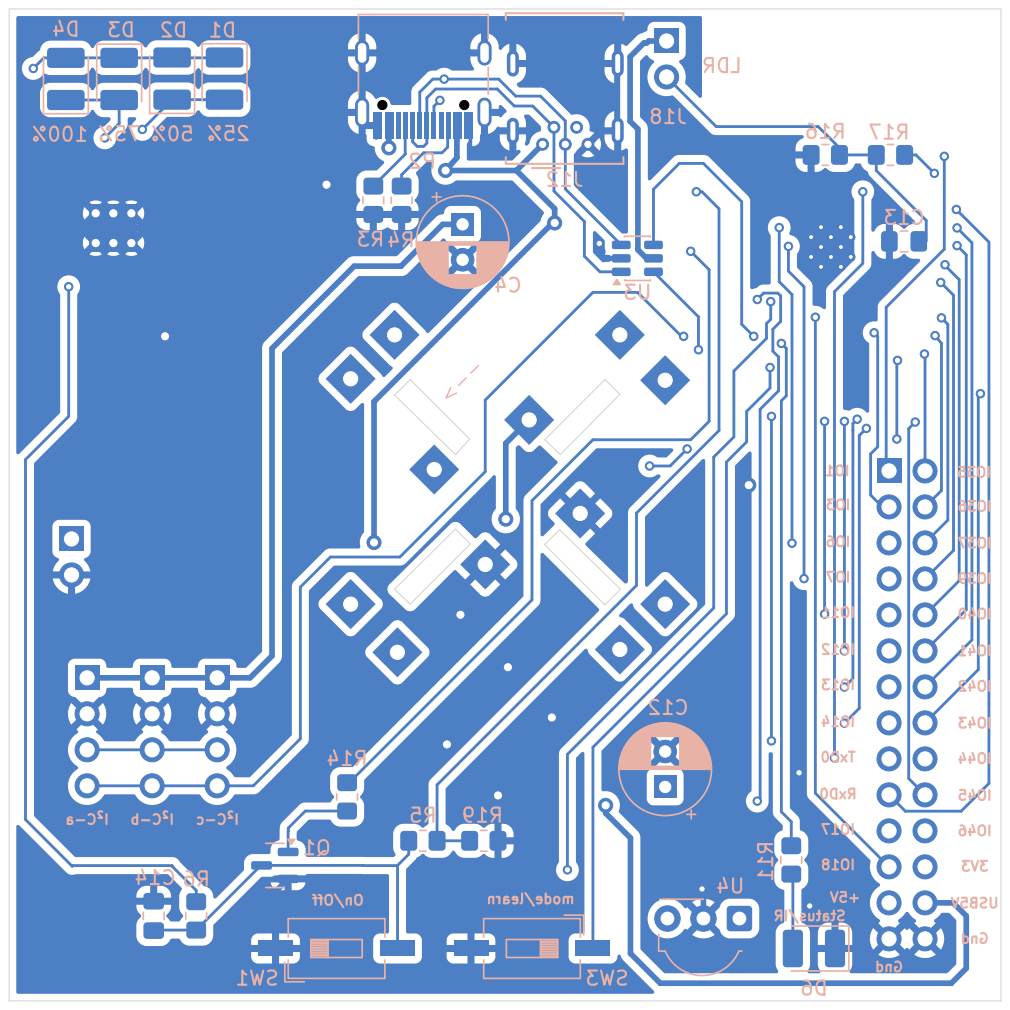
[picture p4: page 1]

I²C-a I²C-b I²C-c Status/IR

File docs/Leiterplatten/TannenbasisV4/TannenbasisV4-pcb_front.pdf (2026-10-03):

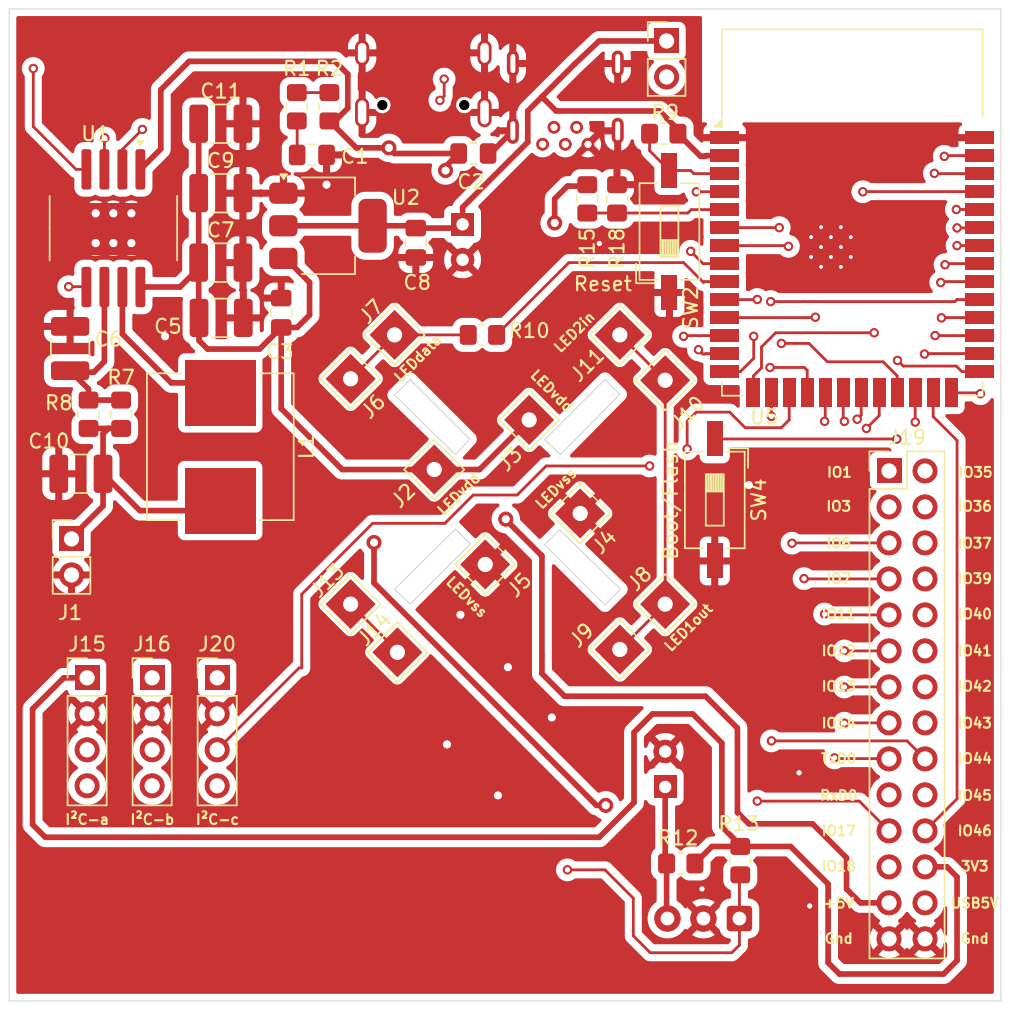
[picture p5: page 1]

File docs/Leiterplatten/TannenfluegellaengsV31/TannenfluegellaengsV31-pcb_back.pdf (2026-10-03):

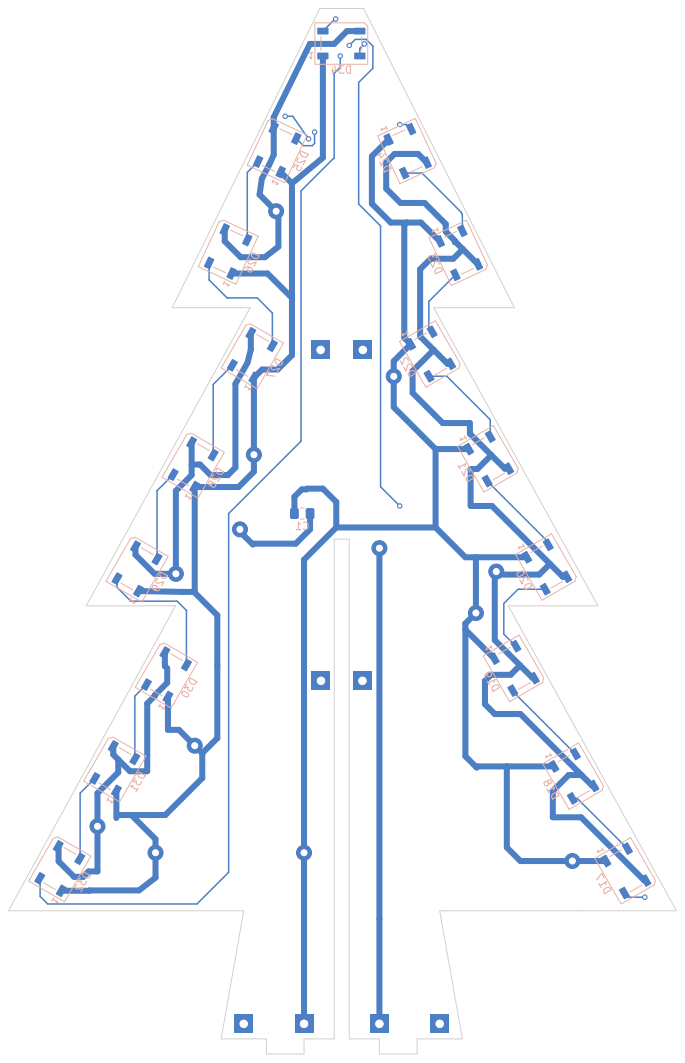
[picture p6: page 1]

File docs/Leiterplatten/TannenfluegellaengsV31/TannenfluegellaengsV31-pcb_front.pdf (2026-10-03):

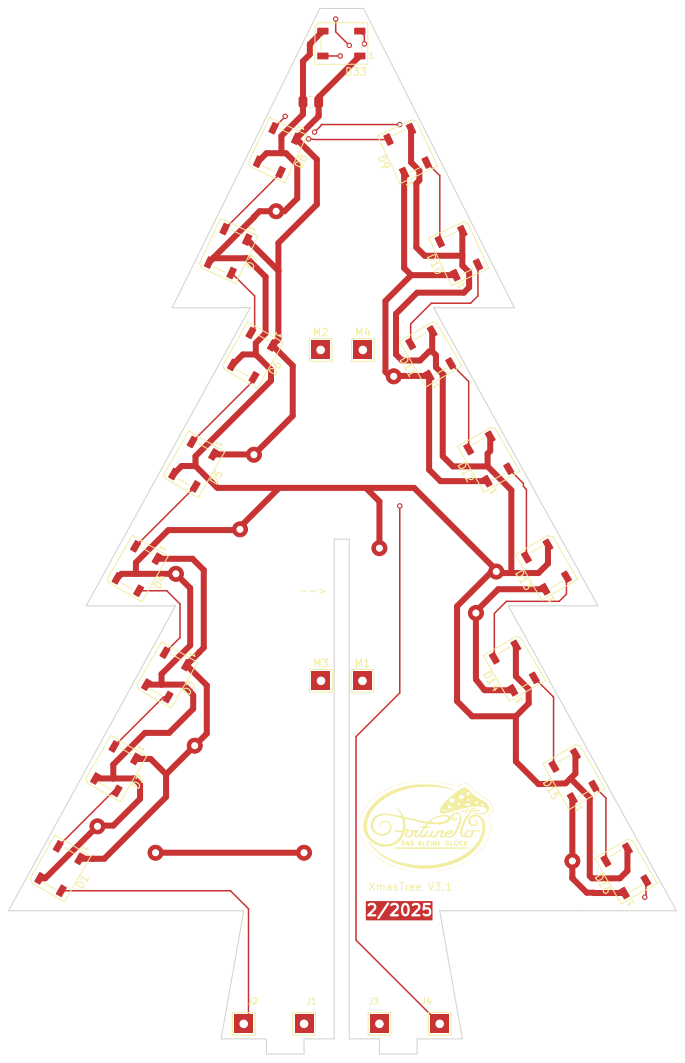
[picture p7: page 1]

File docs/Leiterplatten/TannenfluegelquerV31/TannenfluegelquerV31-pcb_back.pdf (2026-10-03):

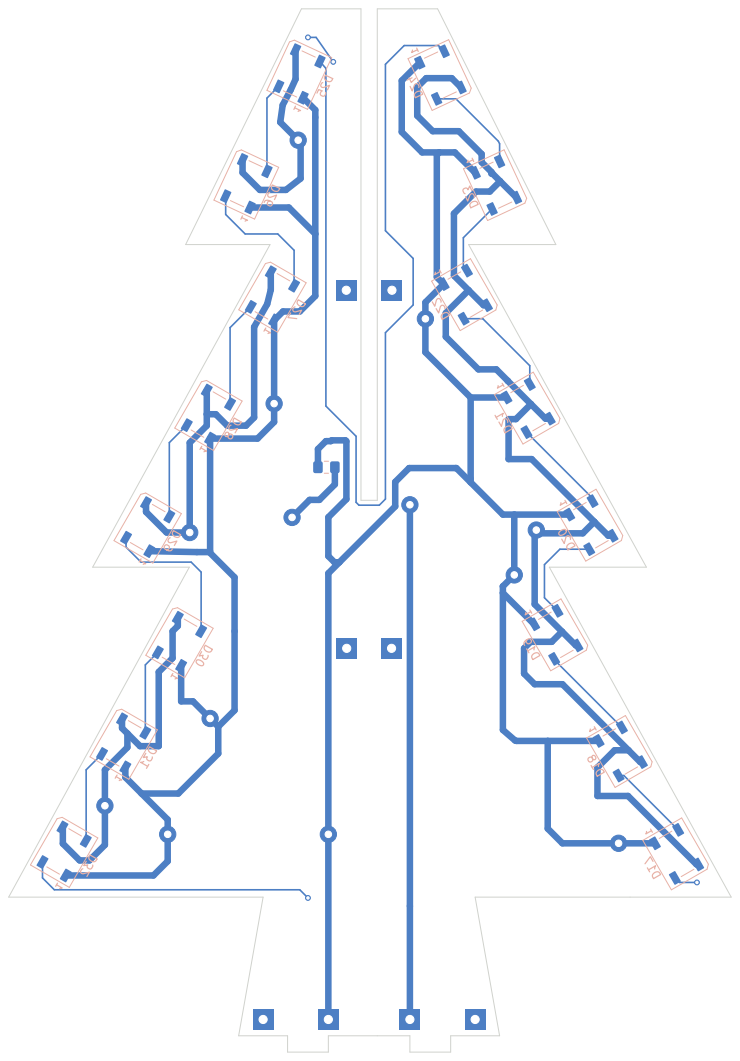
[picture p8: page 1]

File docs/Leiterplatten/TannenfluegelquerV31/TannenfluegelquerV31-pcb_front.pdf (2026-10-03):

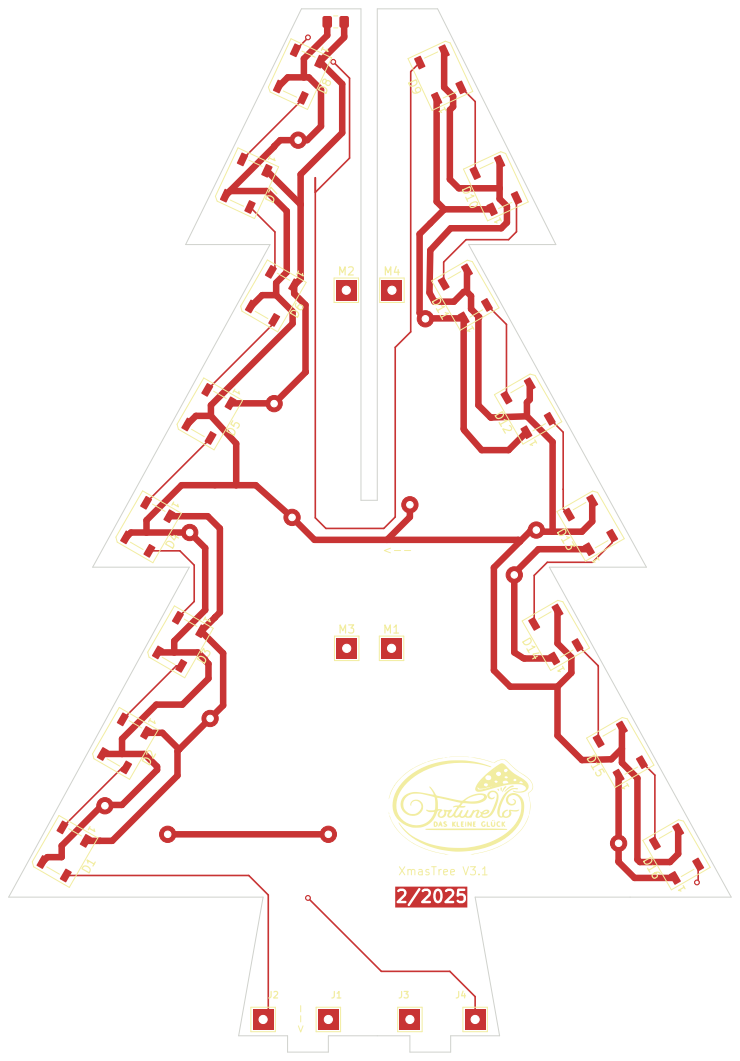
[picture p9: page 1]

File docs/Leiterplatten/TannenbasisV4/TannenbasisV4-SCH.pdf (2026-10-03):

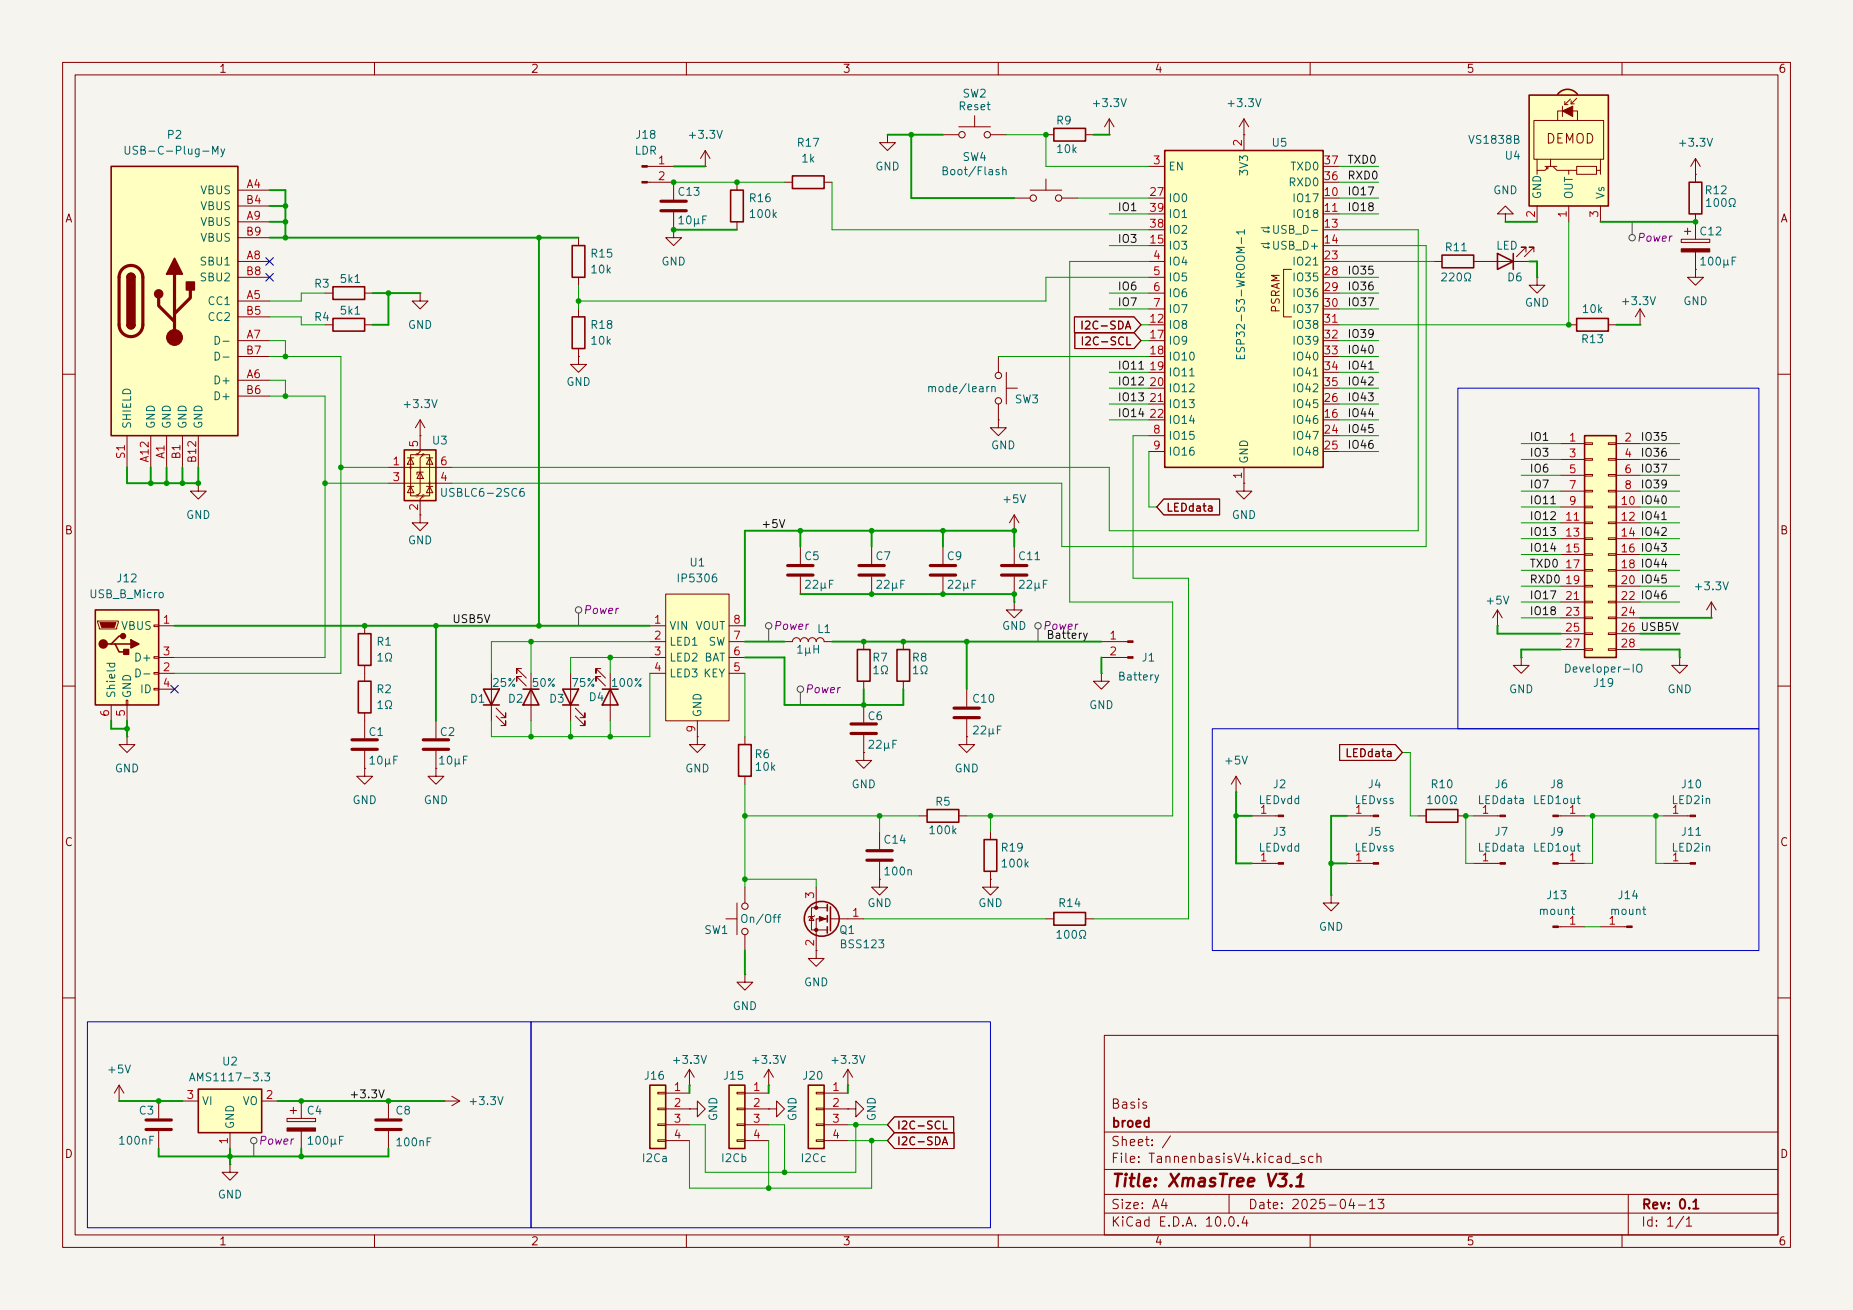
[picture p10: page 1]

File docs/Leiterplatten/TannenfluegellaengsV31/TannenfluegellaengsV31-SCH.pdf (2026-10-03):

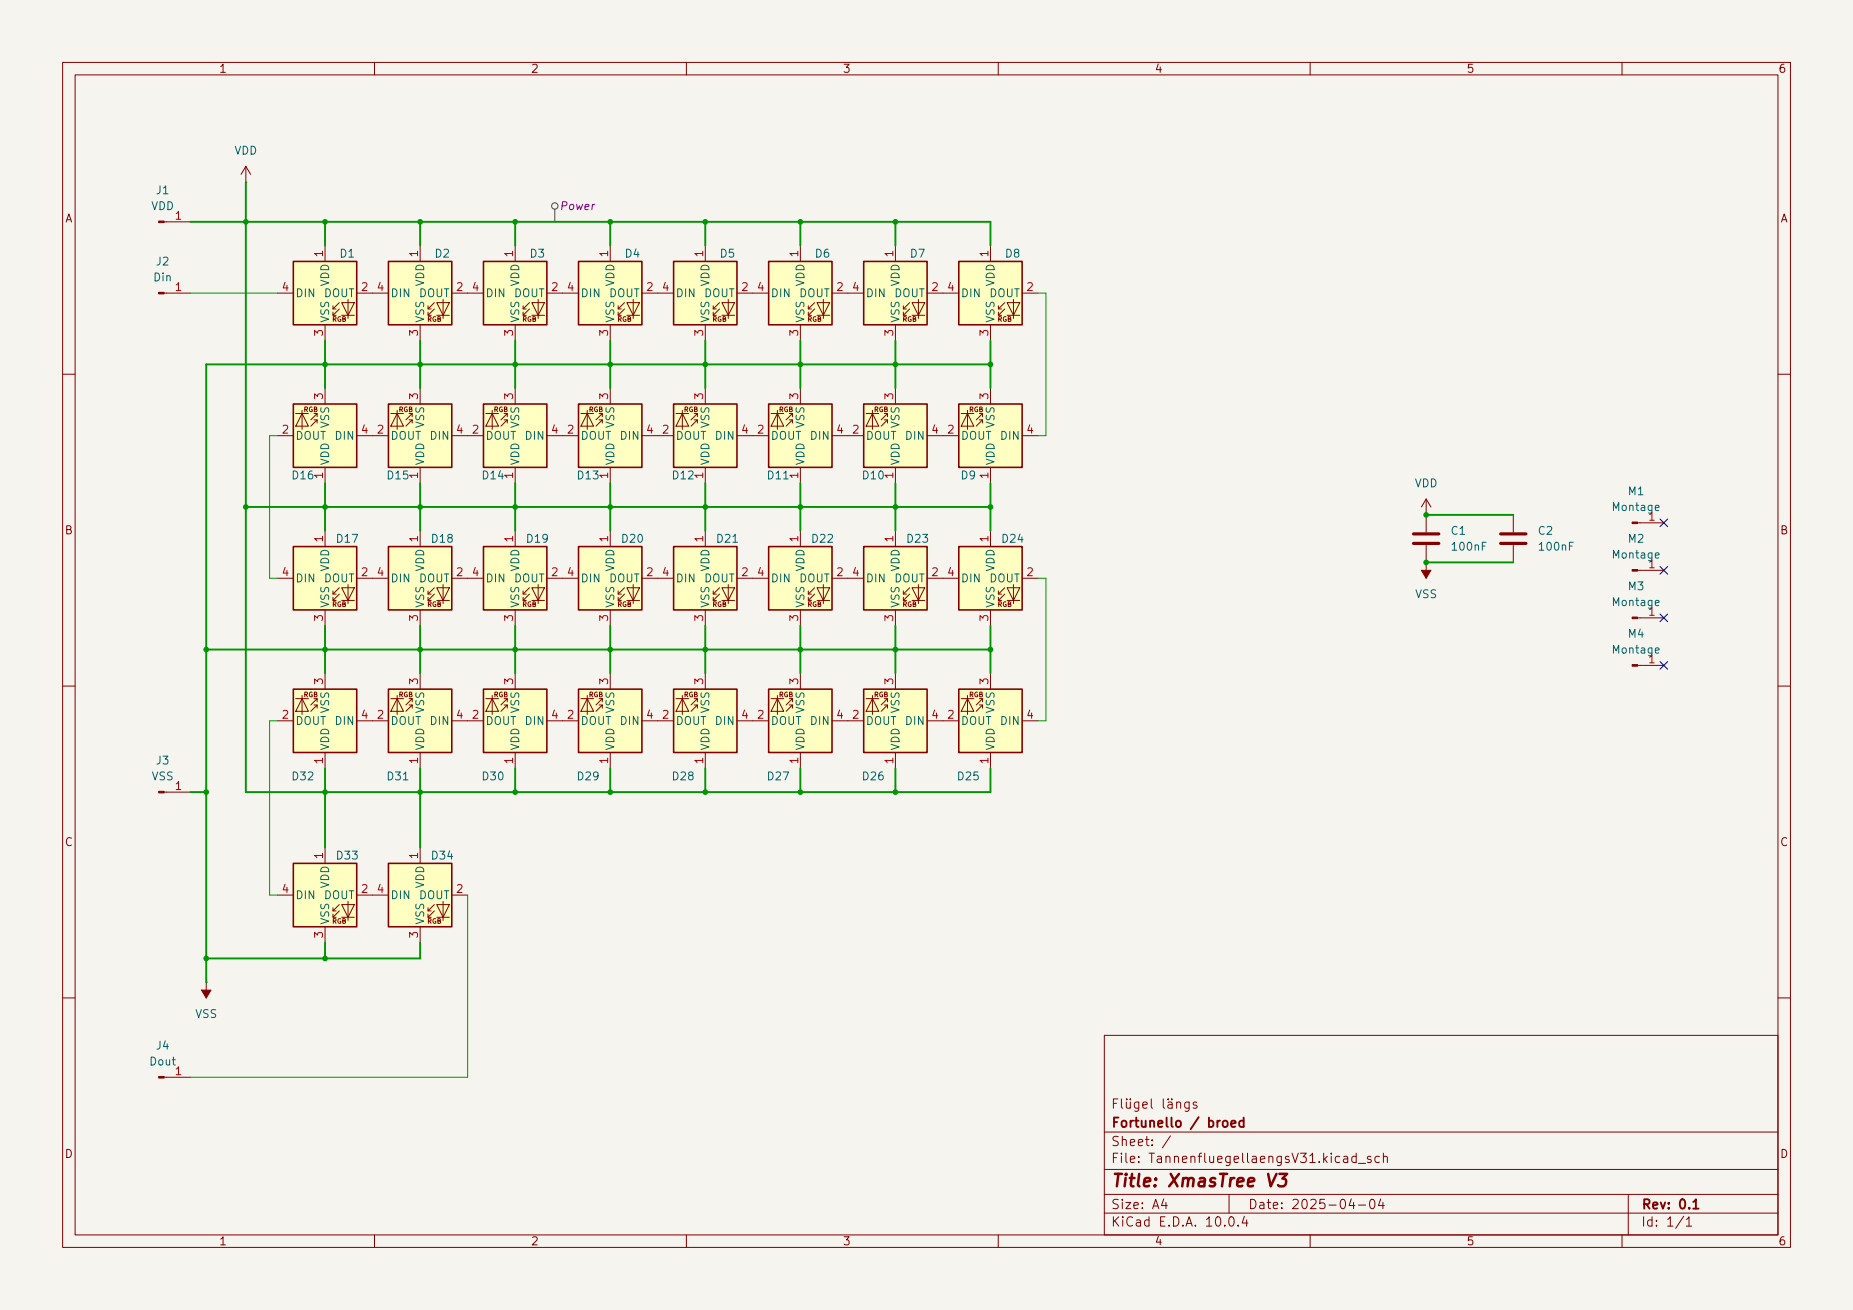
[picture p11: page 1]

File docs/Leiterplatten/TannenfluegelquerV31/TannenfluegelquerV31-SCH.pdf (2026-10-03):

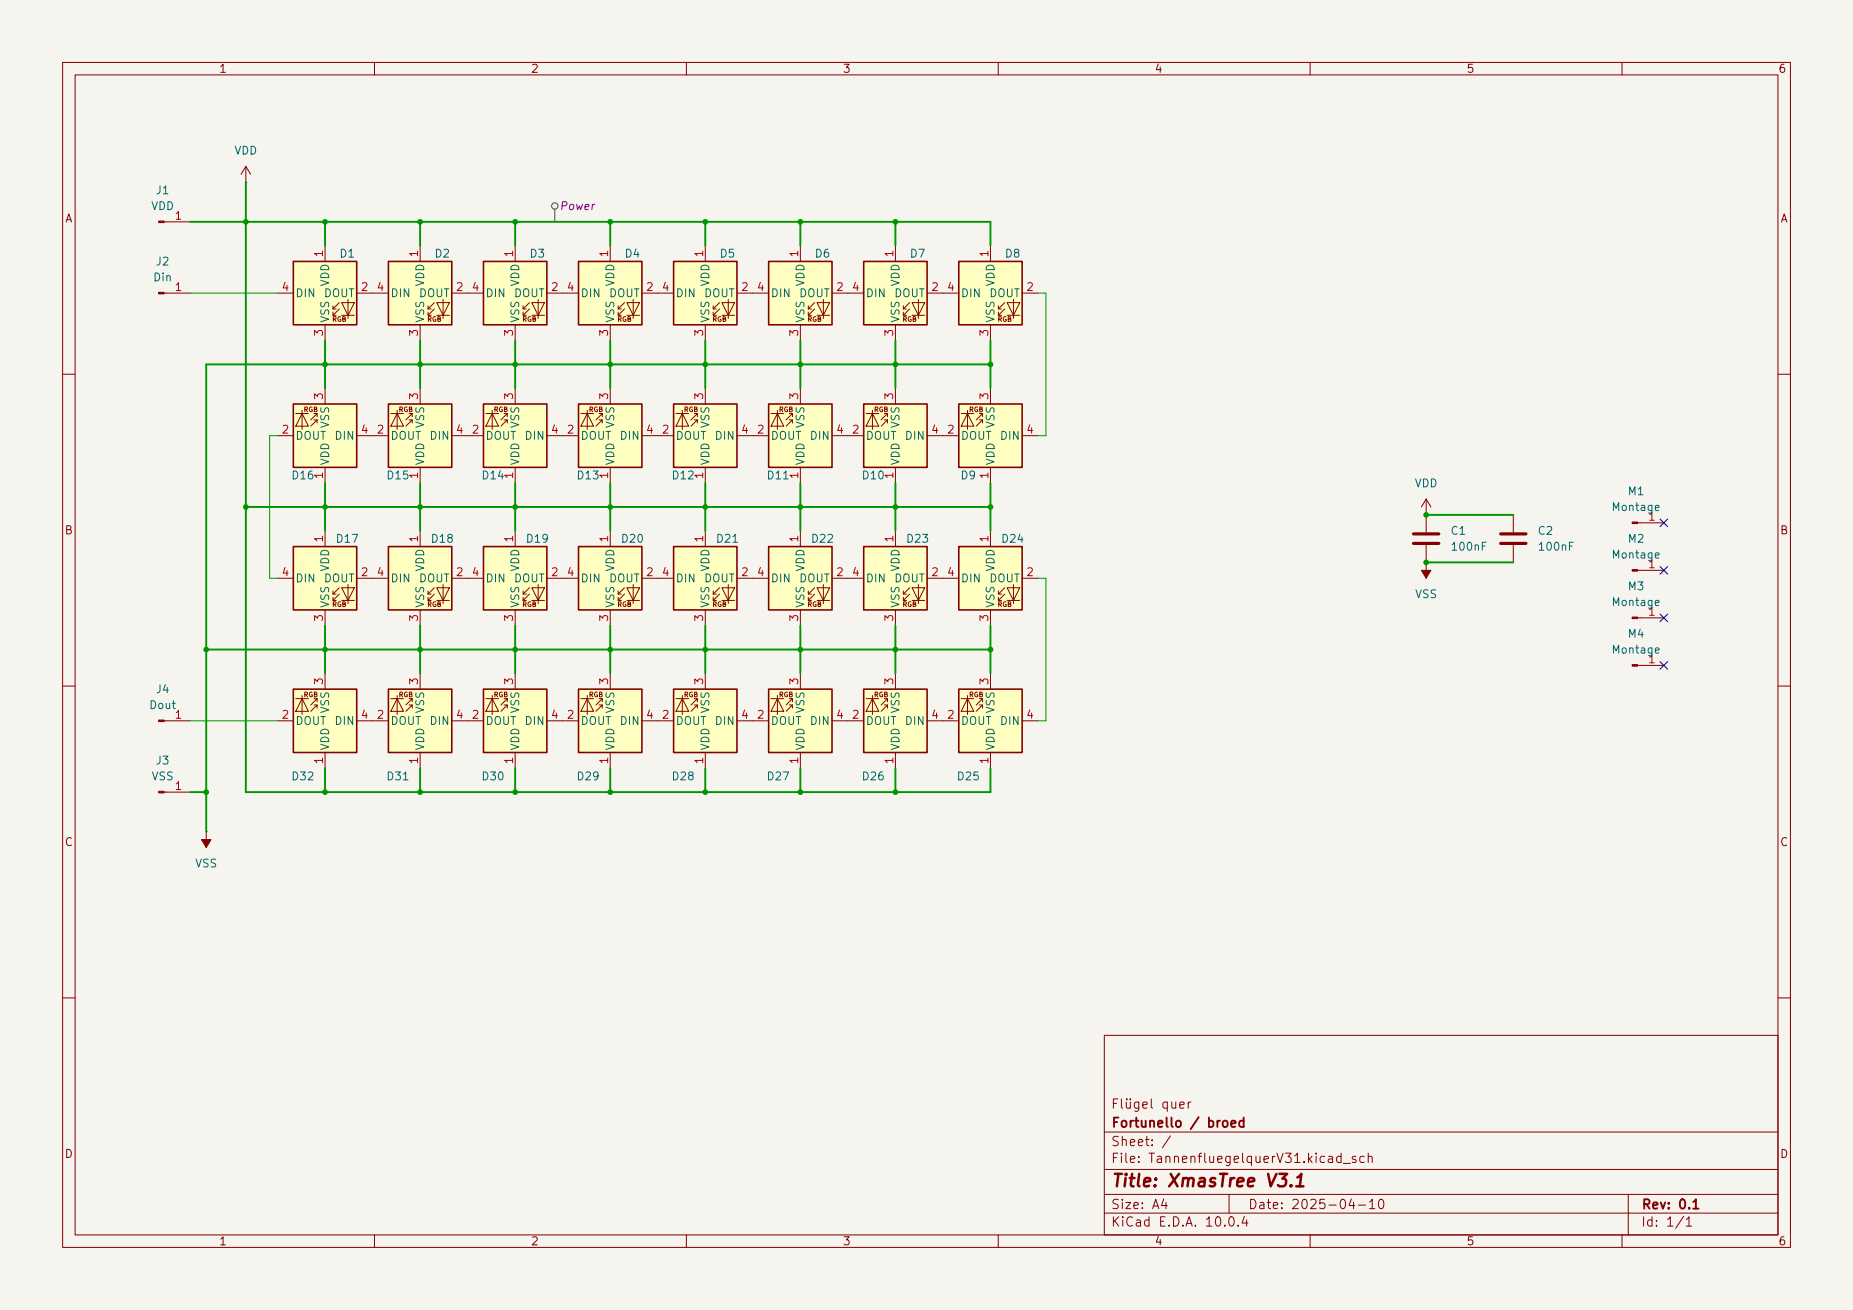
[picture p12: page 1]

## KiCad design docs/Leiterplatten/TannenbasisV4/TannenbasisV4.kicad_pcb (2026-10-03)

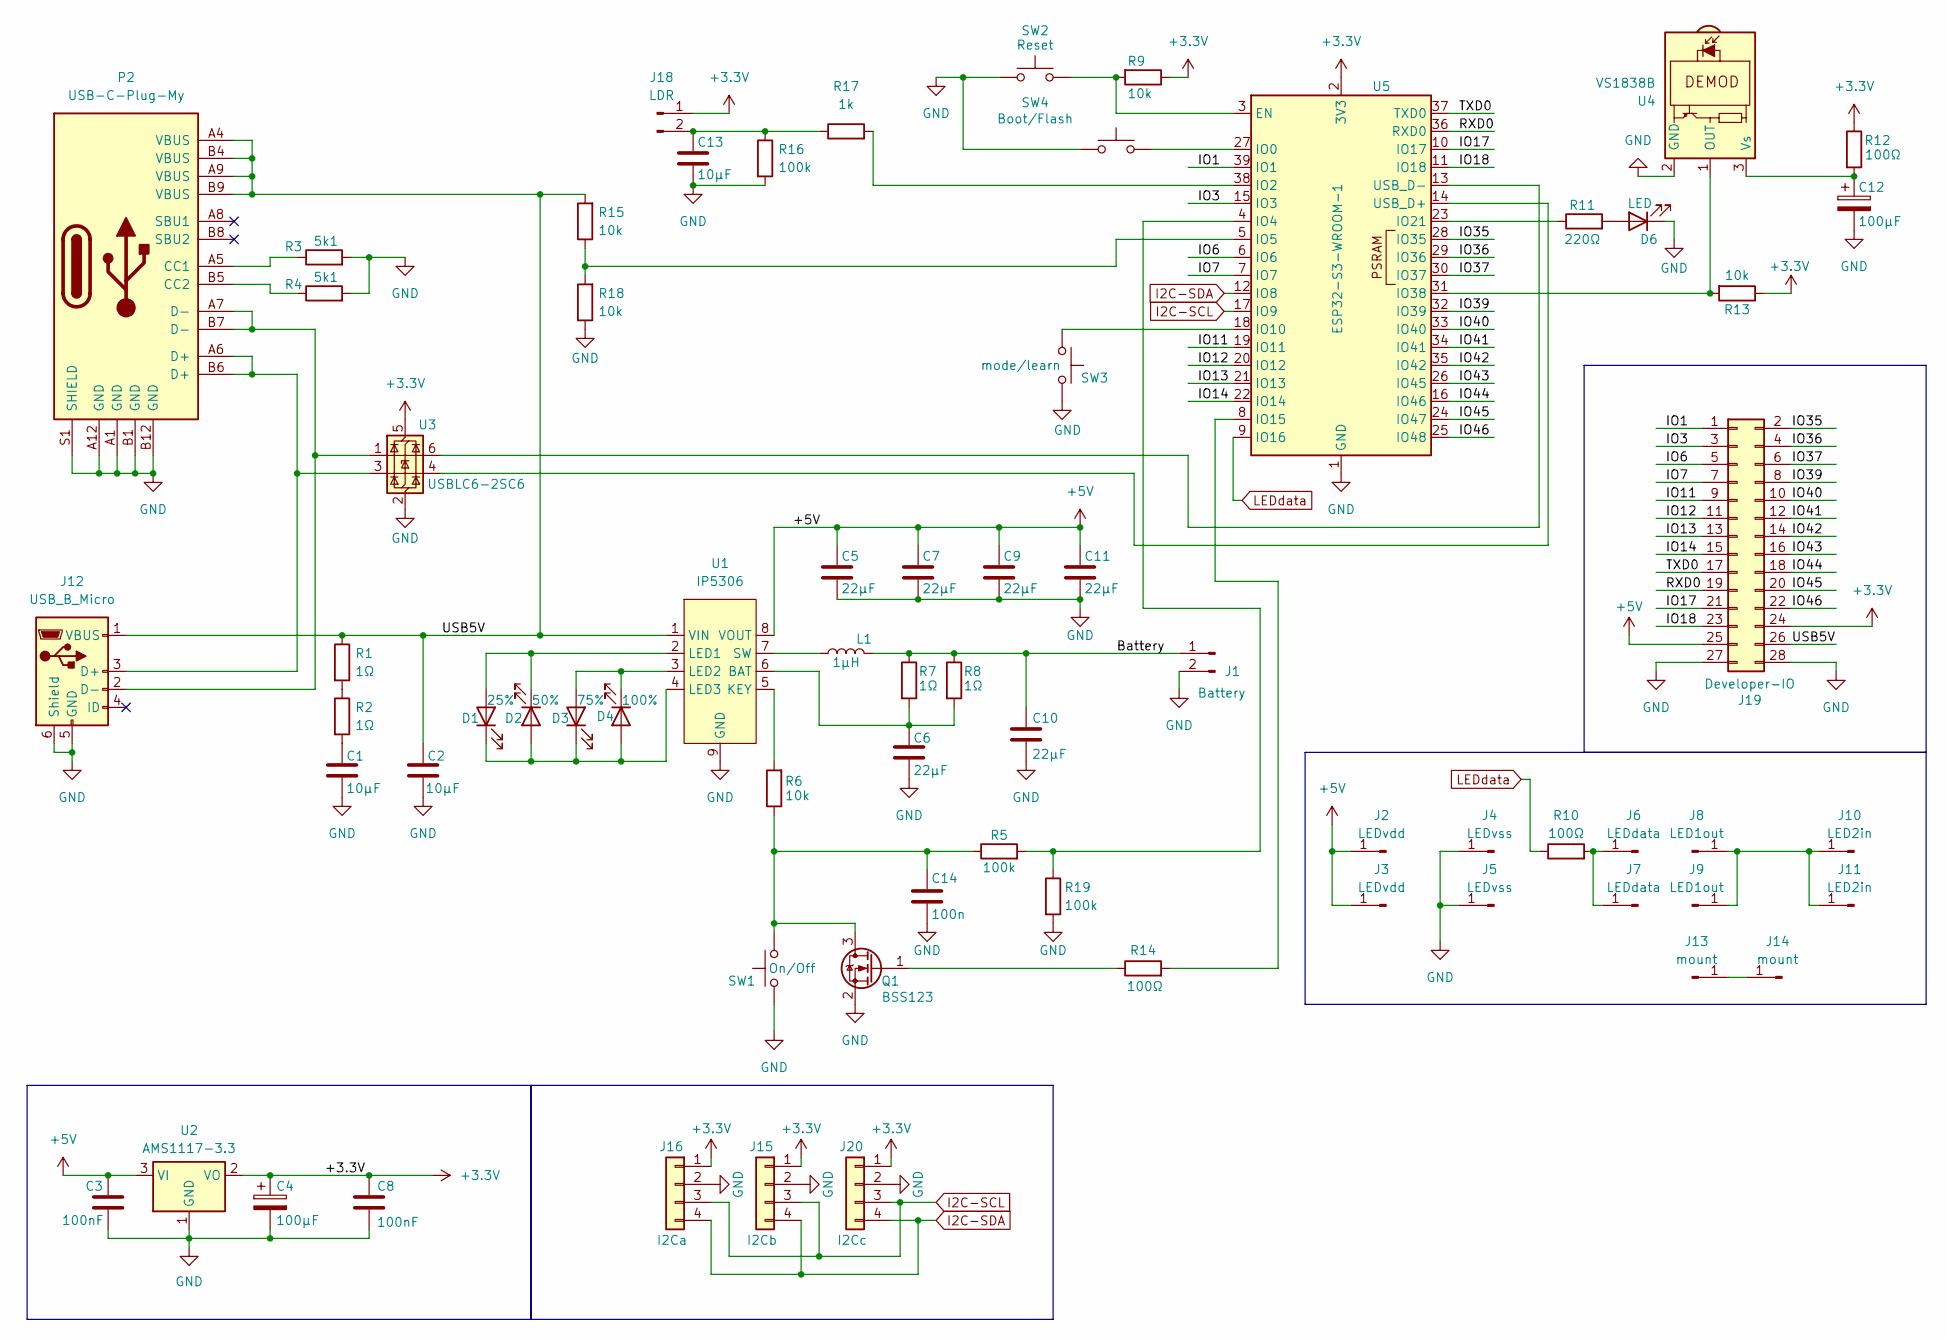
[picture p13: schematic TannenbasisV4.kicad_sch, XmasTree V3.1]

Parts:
C1, C2, C13: 10µF; C_0805_2012Metric_Pad1.18x1.45mm_HandSolder
C3, C8: 100nF; C_0805_2012Metric_Pad1.18x1.45mm_HandSolder
C4, C12: 100µF; CP_Radial_D6.3mm_P2.50mm
C5, C6, C7, C9, C10, C11: 22µF; C_1210_3225Metric_Pad1.33x2.70mm_HandSolder
C14: 100n; C_0805_2012Metric_Pad1.18x1.45mm_HandSolder
D1: 25%; LED_1210_3225Metric_Pad1.42x2.65mm_HandSolder
D2: 50%; LED_1210_3225Metric_Pad1.42x2.65mm_HandSolder
D3: 75%; LED_1210_3225Metric_Pad1.42x2.65mm_HandSolder
D4: 100%; LED_1210_3225Metric_Pad1.42x2.65mm_HandSolder
D6: LED; LED_1210_3225Metric_Pad1.42x2.65mm_HandSolder
J1: Battery; PinHeader_1x02_P2.54mm_Vertical
J2, J3: LEDvdd; solderconnect-1
J4, J5: LEDvss; solderconnect-1
J6, J7: LEDdata; solderconnect-1
J8, J9: LED1out; solderconnect-1
J10, J11: LED2in; solderconnect-1
J12: USB_B_Micro; USB_Micro-B_Pins
J13, J14: mount; solderconnect-1
J15: I2Cb; PinHeader_1x04_P2.54mm_Vertical
J16: I2Ca; PinHeader_1x04_P2.54mm_Vertical
J18: LDR; PinHeader_1x02_P2.54mm_Vertical
J19: Developer-IO; PinHeader_2x14_P2.54mm_Vertical
J20: I2Cc; PinHeader_1x04_P2.54mm_Vertical
L1: 1µH; MyPowerCoil
P2: USB-C-Plug-My; MyUSB-C
Q1: BSS123; SOT-23
R1, R2, R7, R8: 1Ω; R_0805_2012Metric_Pad1.20x1.40mm_HandSolder
R3, R4: 5k1; R_0805_2012Metric_Pad1.20x1.40mm_HandSolder
R5, R16, R19: 100k; R_0805_2012Metric_Pad1.20x1.40mm_HandSolder
R6, R9, R13, R15, R18: 10k; R_0805_2012Metric_Pad1.20x1.40mm_HandSolder
R10, R12, R14: 100Ω; R_0805_2012Metric_Pad1.20x1.40mm_HandSolder
R11: 220Ω; R_0805_2012Metric_Pad1.20x1.40mm_HandSolder
R17: 1k; R_0805_2012Metric_Pad1.20x1.40mm_HandSolder
SW1: On/Off; SW_DIP_SPSTx01_Slide_6.7x4.1mm_W8.61mm_P2.54mm_LowProfile
SW2: Reset; SW_DIP_SPSTx01_Slide_6.7x4.1mm_W8.61mm_P2.54mm_LowProfile
SW3: mode/learn; SW_DIP_SPSTx01_Slide_6.7x4.1mm_W8.61mm_P2.54mm_LowProfile
SW4: Boot/Flash; SW_DIP_SPSTx01_Slide_6.7x4.1mm_W8.61mm_P2.54mm_LowProfile
U1: IP5306
U2: AMS1117-3.3; SOT-223-3_TabPin2
U3: USBLC6-2SC6; SOT-23-6
U4: VS1838B; Vishay_MOLD-3Pin
U5: ESP32-S3-WROOM-1

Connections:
+3.3V: C4.1, C8.1, J15.1, J16.1, J18.1, J19.24, J20.1, R9.1, R12.1, R13.1, U2.2 (VO), U3.5 (VBUS), U5.2 (3V3)
+5V: C3.1, C5.1, C7.1, C9.1, C11.1, J2.1, J3.1, J19.25, U1.8 (VOUT), U2.3 (VI)
/Battery: C10.1, J1.1, L1.2, R7.1, R8.1
/IO1: J19.1, U5.39 (IO1)
/IO3: J19.3, U5.15 (IO3)
/IO6: J19.5, U5.6 (IO6)
/IO7: J19.7, U5.7 (IO7)
/IO11: J19.9, U5.19 (IO11)
/IO12: J19.11, U5.20 (IO12)
/IO13: J19.13, U5.21 (IO13)
/IO14: J19.15, U5.22 (IO14)
/IO17: J19.21, U5.10 (IO17)
/IO18: J19.23, U5.11 (IO18)
/IO35: J19.2, U5.28 (IO35)
/IO36: J19.4, U5.29 (IO36)
/IO37: J19.6, U5.30 (IO37)
/IO39: J19.8, U5.32 (IO39)
/IO40: J19.10, U5.33 (IO40)
/IO41: J19.12, U5.34 (IO41)
/IO42: J19.14, U5.35 (IO42)
/IO43: J19.16, U5.26 (IO45)
/IO44: J19.18, U5.16 (IO46)
/IO45: J19.20, U5.24 (IO47)
/IO46: J19.22, U5.25 (IO48)
/RXD0: J19.19, U5.36 (RXD0)
/TXD0: J19.17, U5.37 (TXD0)
/USB5V: C2.1, J12.1 (VBUS), J19.26, P2.A4 (VBUS), P2.A9 (VBUS), P2.B4 (VBUS), P2.B9 (VBUS), R1.1, R15.2, U1.1 (VIN)
GND: C1.2, C2.2, C3.2, C4.2, C5.2, C6.2, C7.2, C8.2, C9.2, C10.2, C11.2, C12.2, C13.2, C14.2, D6.1 (K), J1.2, J4.1, J5.1, J12.5 (GND), J12.6 (Shield), J15.2, J16.2, J19.27, J19.28, J20.2, P2.A1 (GND), P2.A12 (GND), P2.B1 (GND), P2.B12 (GND), P2.S1 (SHIELD), Q1.2 (S), R3.2, R4.2, R16.2, R18.1, R19.2, SW1.1, SW2.1, SW3.2, SW4.2, U1.9 (GND), U2.1 (GND), U3.2 (GND), U4.2 (GND), U5.1 (GND), U5.40 (GND), U5.41 (GND)
I2C-SCL: J15.3, J16.3, J20.3, U5.17 (IO9)
I2C-SDA: J15.4, J16.4, J20.4, U5.12 (IO8)
LEDdata: R10.1, U5.9 (IO16)
unnamed: C1.1, R2.2
unnamed: D1.2 (A), D2.1 (K), U1.2 (LED1)
unnamed: D1.1 (K), D2.2 (A), D3.1 (K), D4.2 (A), U1.4 (LED3)
unnamed: D3.2 (A), D4.1 (K), U1.3 (LED2)
unnamed: D6.2 (A), R11.2
unnamed: J6.1, J7.1, R10.2
unnamed: J8.1, J9.1, J10.1, J11.1
unnamed: J12.3 (D+), P2.A6 (D+), P2.B6 (D+), U3.3 (I/O2)
unnamed: J12.2 (D-), P2.A7 (D-), P2.B7 (D-), U3.1 (I/O1)
unnamed: J13.1, J14.1
unnamed: C13.1, J18.2, R16.1, R17.1
unnamed: P2.A5 (CC1), R3.1
unnamed: P2.B5 (CC2), R4.1
unnamed: C14.1, Q1.3 (D), R5.1, R6.1, SW1.2
unnamed: Q1.1 (G), R14.1
unnamed: R1.2, R2.1
unnamed: C6.1, R7.2, R8.2, U1.6 (BAT)
unnamed: R6.2, U1.5 (KEY)
unnamed: L1.1, U1.7 (SW)
unnamed: R13.2, U4.1 (OUT), U5.31 (IO38)
unnamed: C12.1, R12.2, U4.3 (Vs)
unnamed: R9.2, SW2.2, U5.3 (EN)
unnamed: SW4.1, U5.27 (IO0)
unnamed: R17.2, U5.38 (IO2)
unnamed: R5.2, R19.1, U5.4 (IO4)
unnamed: R15.1, R18.2, U5.5 (IO5)
unnamed: SW3.1, U5.18 (IO10)
unnamed: R14.2, U5.8 (IO15)
unnamed: R11.1, U5.23 (IO21)
unnamed: U3.4 (I/O2), U5.14 (USB_D+)
unnamed: U3.6 (I/O1), U5.13 (USB_D-)

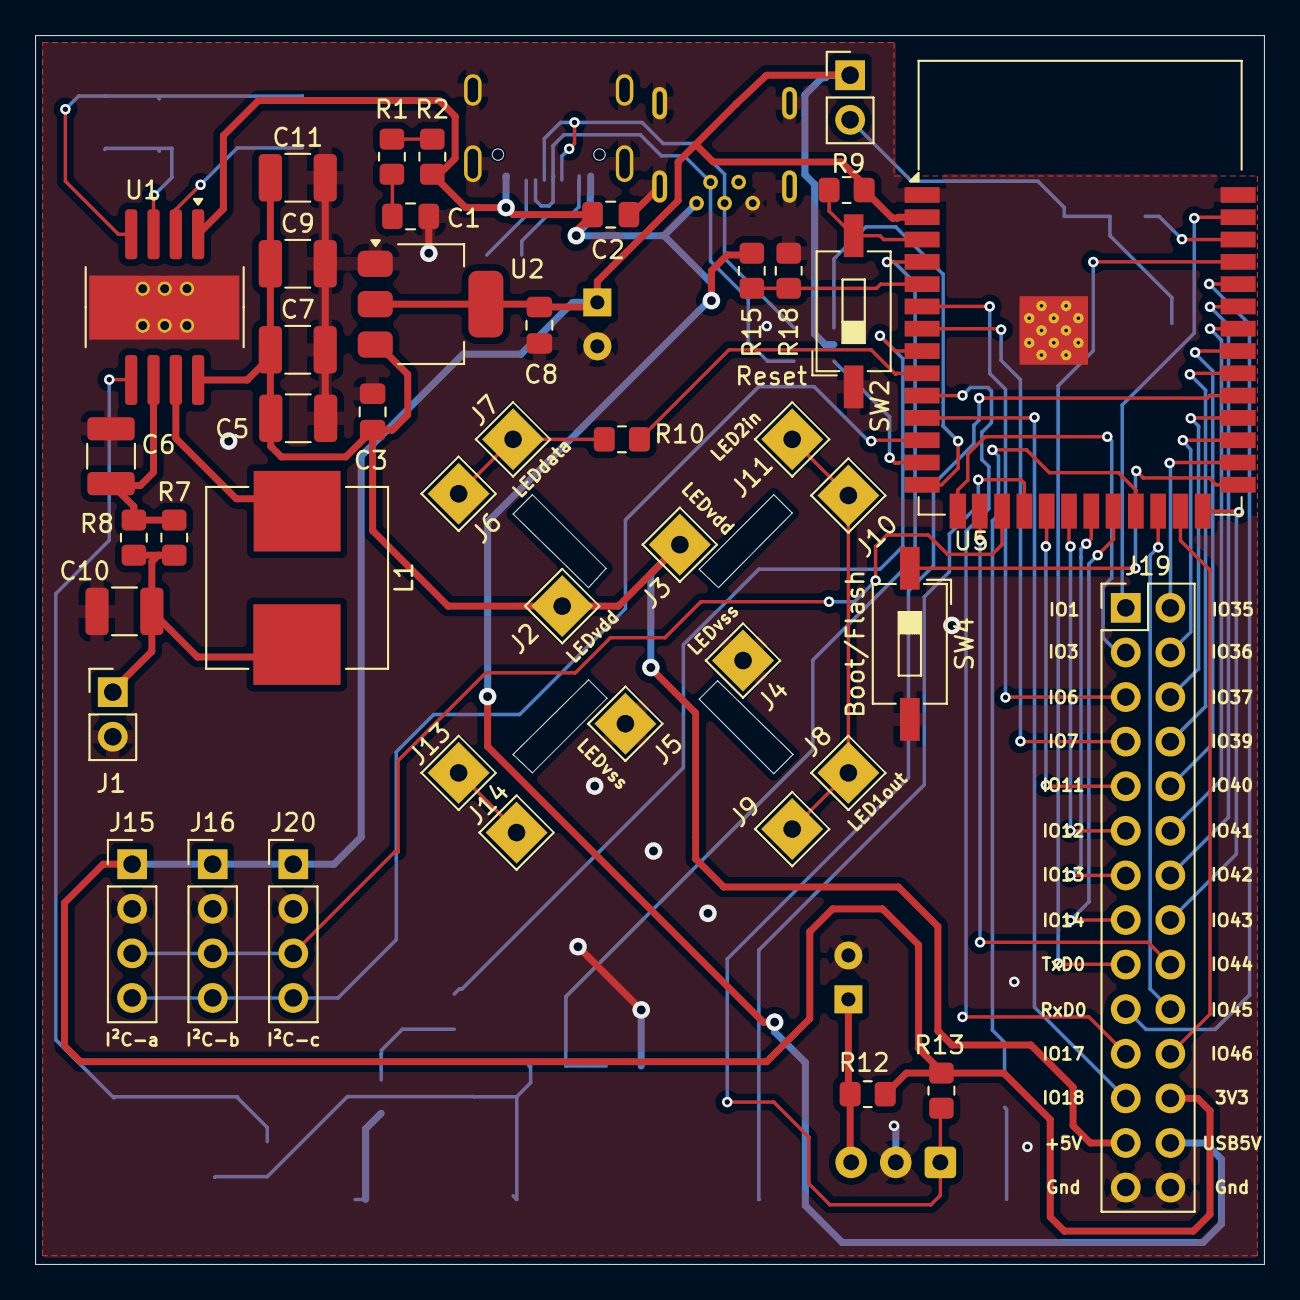
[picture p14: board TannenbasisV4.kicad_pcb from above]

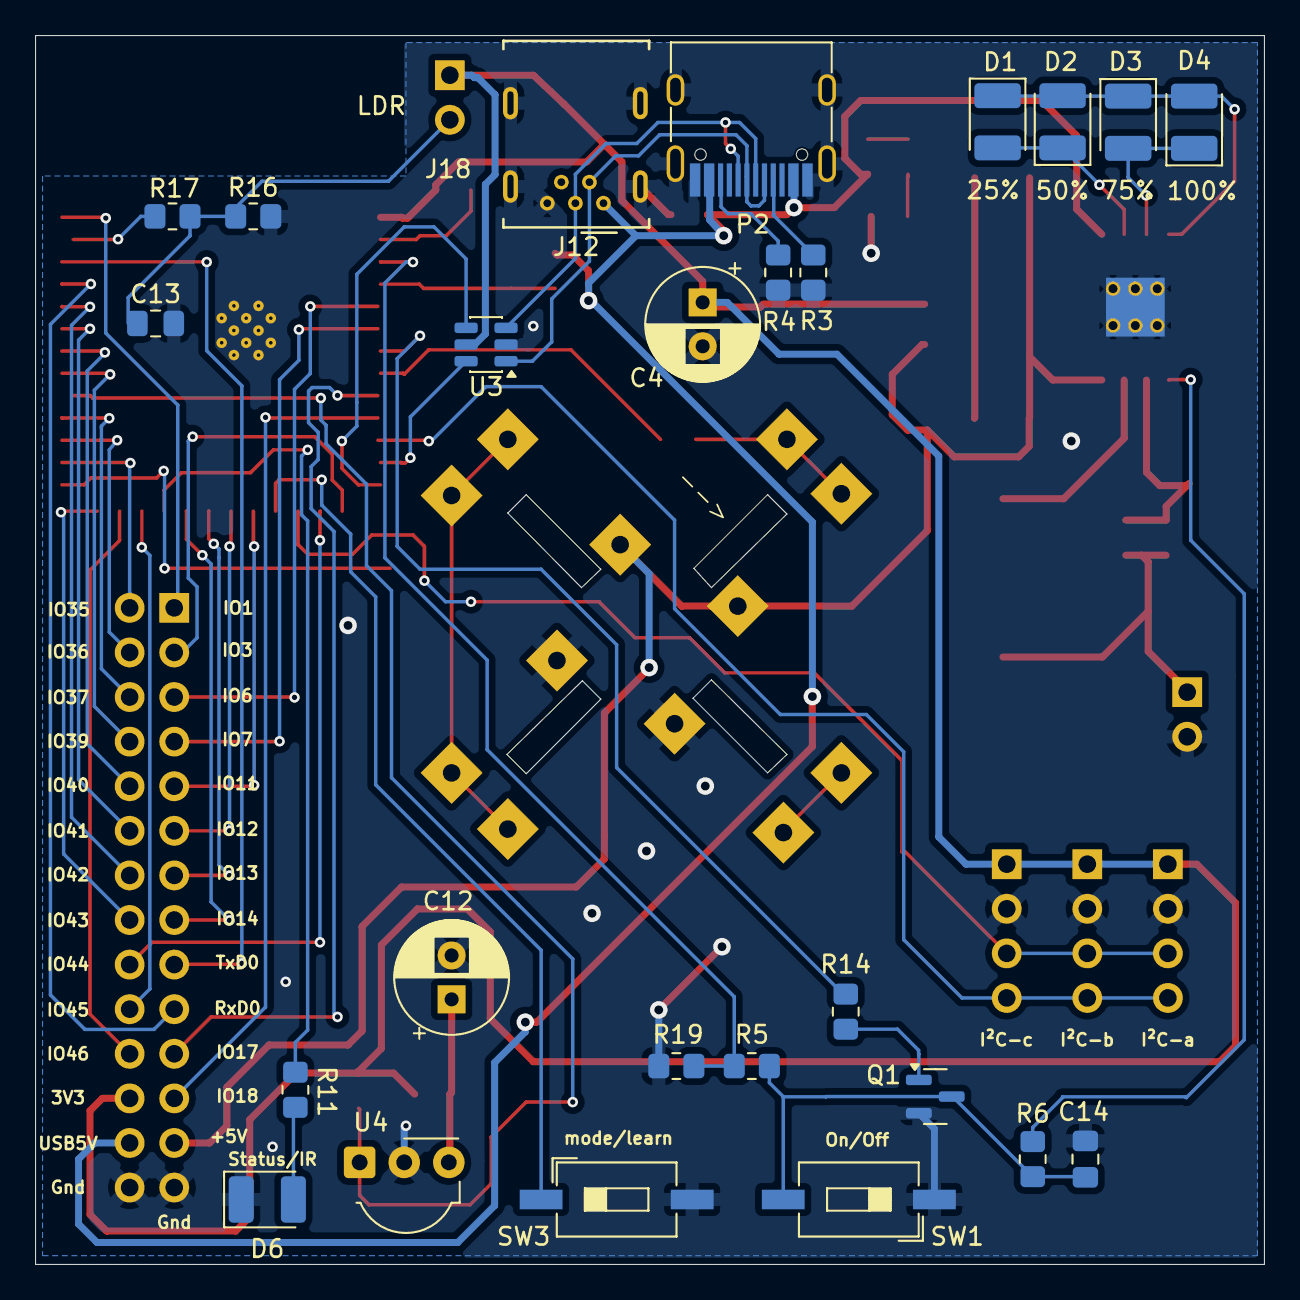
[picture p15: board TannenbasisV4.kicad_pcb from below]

Board: 2 copper layers, 70.0 x 70.0 mm, 69 parts (25 on the bottom side), 62 nets.

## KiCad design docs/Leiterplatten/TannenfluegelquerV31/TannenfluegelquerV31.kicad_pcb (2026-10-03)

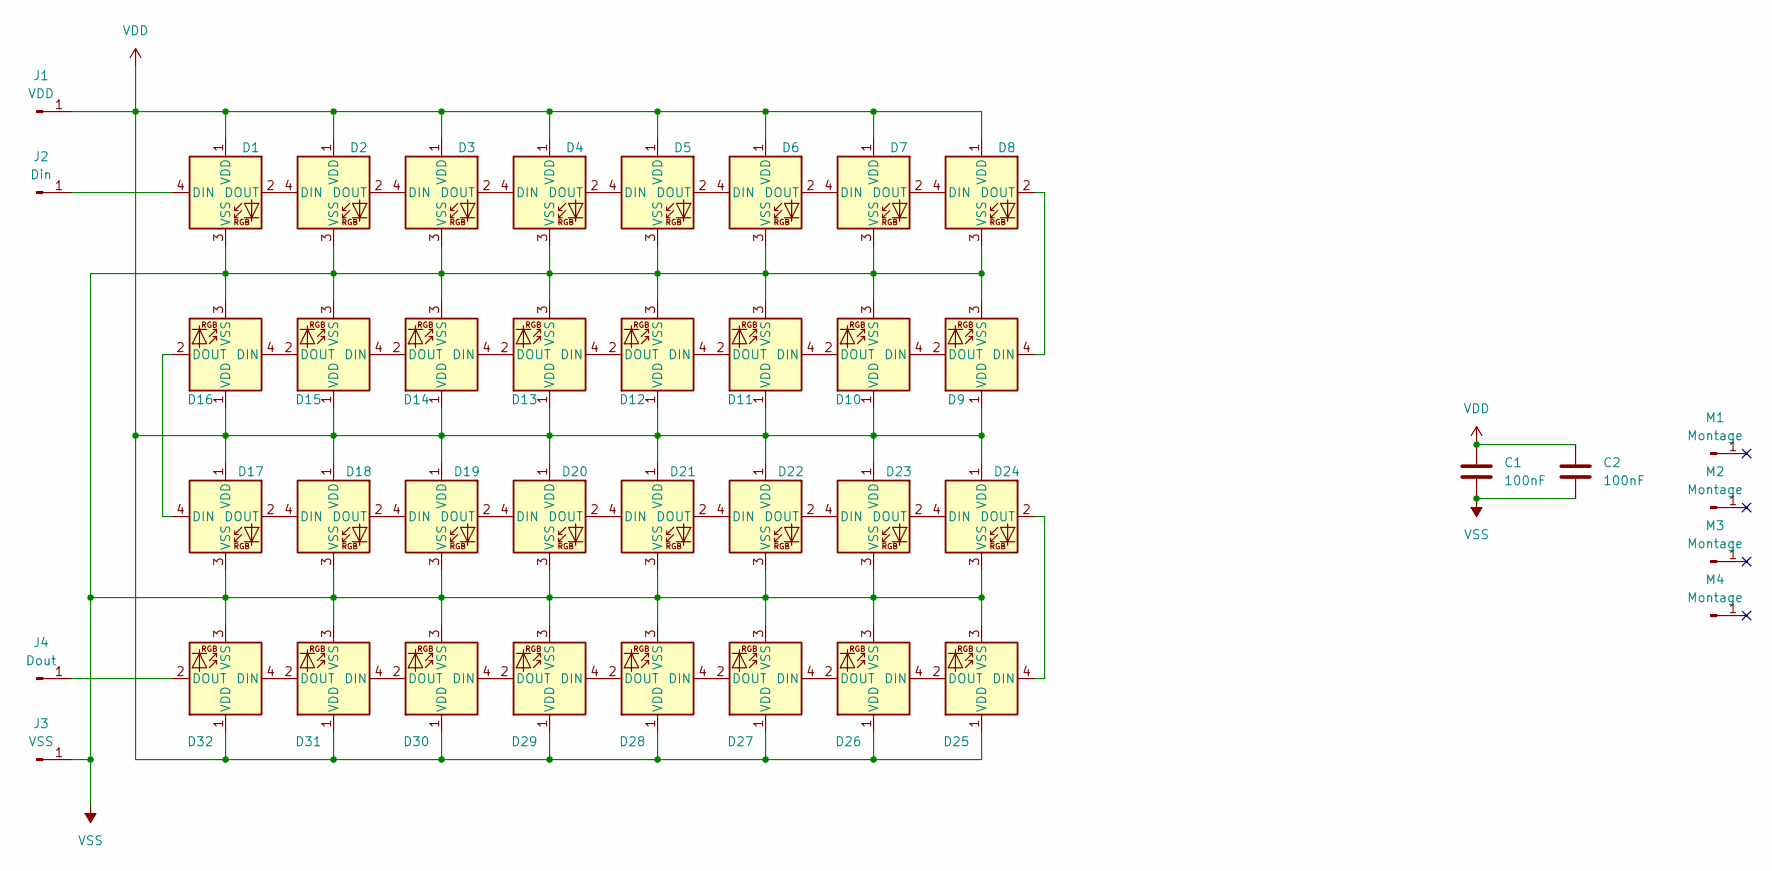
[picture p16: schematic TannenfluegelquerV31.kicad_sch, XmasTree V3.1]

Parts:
C1, C2: 100nF; C_0805_2012Metric_Pad1.18x1.45mm_HandSolder
D1, D2, D3, D4, D5, D6, D7, D8, D9, D10, D11, D12, D13, D14, D15, D16, D17, D18, D19, D20, D21, D22, D23, D24, D25, D26, D27, D28, D29, D30, D31, D32: WS2812B; LED_WS2812B_PLCC4_5.0x5.0mm_P3.2mm
J1: VDD; solderconnect-1
J2: Din; solderconnect-1
J3: VSS; solderconnect-1
J4: Dout; solderconnect-1
M1, M2, M3, M4: Montage; solderconnect-1

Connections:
unnamed: D1.4 (DIN), J2.1
unnamed: D1.2 (DOUT), D2.4 (DIN)
unnamed: D2.2 (DOUT), D3.4 (DIN)
unnamed: D3.2 (DOUT), D4.4 (DIN)
unnamed: D4.2 (DOUT), D5.4 (DIN)
unnamed: D5.2 (DOUT), D6.4 (DIN)
unnamed: D6.2 (DOUT), D7.4 (DIN)
unnamed: D7.2 (DOUT), D8.4 (DIN)
unnamed: D8.2 (DOUT), D9.4 (DIN)
unnamed: D9.2 (DOUT), D10.4 (DIN)
unnamed: D10.2 (DOUT), D11.4 (DIN)
unnamed: D11.2 (DOUT), D12.4 (DIN)
unnamed: D12.2 (DOUT), D13.4 (DIN)
unnamed: D13.2 (DOUT), D14.4 (DIN)
unnamed: D14.2 (DOUT), D15.4 (DIN)
unnamed: D15.2 (DOUT), D16.4 (DIN)
unnamed: D16.2 (DOUT), D17.4 (DIN)
unnamed: D17.2 (DOUT), D18.4 (DIN)
unnamed: D18.2 (DOUT), D19.4 (DIN)
unnamed: D19.2 (DOUT), D20.4 (DIN)
unnamed: D20.2 (DOUT), D21.4 (DIN)
unnamed: D21.2 (DOUT), D22.4 (DIN)
unnamed: D22.2 (DOUT), D23.4 (DIN)
unnamed: D23.2 (DOUT), D24.4 (DIN)
unnamed: D24.2 (DOUT), D25.4 (DIN)
unnamed: D25.2 (DOUT), D26.4 (DIN)
unnamed: D26.2 (DOUT), D27.4 (DIN)
unnamed: D27.2 (DOUT), D28.4 (DIN)
unnamed: D28.2 (DOUT), D29.4 (DIN)
unnamed: D29.2 (DOUT), D30.4 (DIN)
unnamed: D30.2 (DOUT), D31.4 (DIN)
unnamed: D31.2 (DOUT), D32.4 (DIN)
unnamed: D32.2 (DOUT), J4.1
VDD: C1.1, C2.1, D1.1 (VDD), D2.1 (VDD), D3.1 (VDD), D4.1 (VDD), D5.1 (VDD), D6.1 (VDD), D7.1 (VDD), D8.1 (VDD), D9.1 (VDD), D10.1 (VDD), D11.1 (VDD), D12.1 (VDD), D13.1 (VDD), D14.1 (VDD), D15.1 (VDD), D16.1 (VDD), D17.1 (VDD), D18.1 (VDD), D19.1 (VDD), D20.1 (VDD), D21.1 (VDD), D22.1 (VDD), D23.1 (VDD), D24.1 (VDD), D25.1 (VDD), D26.1 (VDD), D27.1 (VDD), D28.1 (VDD), D29.1 (VDD), D30.1 (VDD), D31.1 (VDD), D32.1 (VDD), J1.1
VSS: C1.2, C2.2, D1.3 (VSS), D2.3 (VSS), D3.3 (VSS), D4.3 (VSS), D5.3 (VSS), D6.3 (VSS), D7.3 (VSS), D8.3 (VSS), D9.3 (VSS), D10.3 (VSS), D11.3 (VSS), D12.3 (VSS), D13.3 (VSS), D14.3 (VSS), D15.3 (VSS), D16.3 (VSS), D17.3 (VSS), D18.3 (VSS), D19.3 (VSS), D20.3 (VSS), D21.3 (VSS), D22.3 (VSS), D23.3 (VSS), D24.3 (VSS), D25.3 (VSS), D26.3 (VSS), D27.3 (VSS), D28.3 (VSS), D29.3 (VSS), D30.3 (VSS), D31.3 (VSS), D32.3 (VSS), J3.1

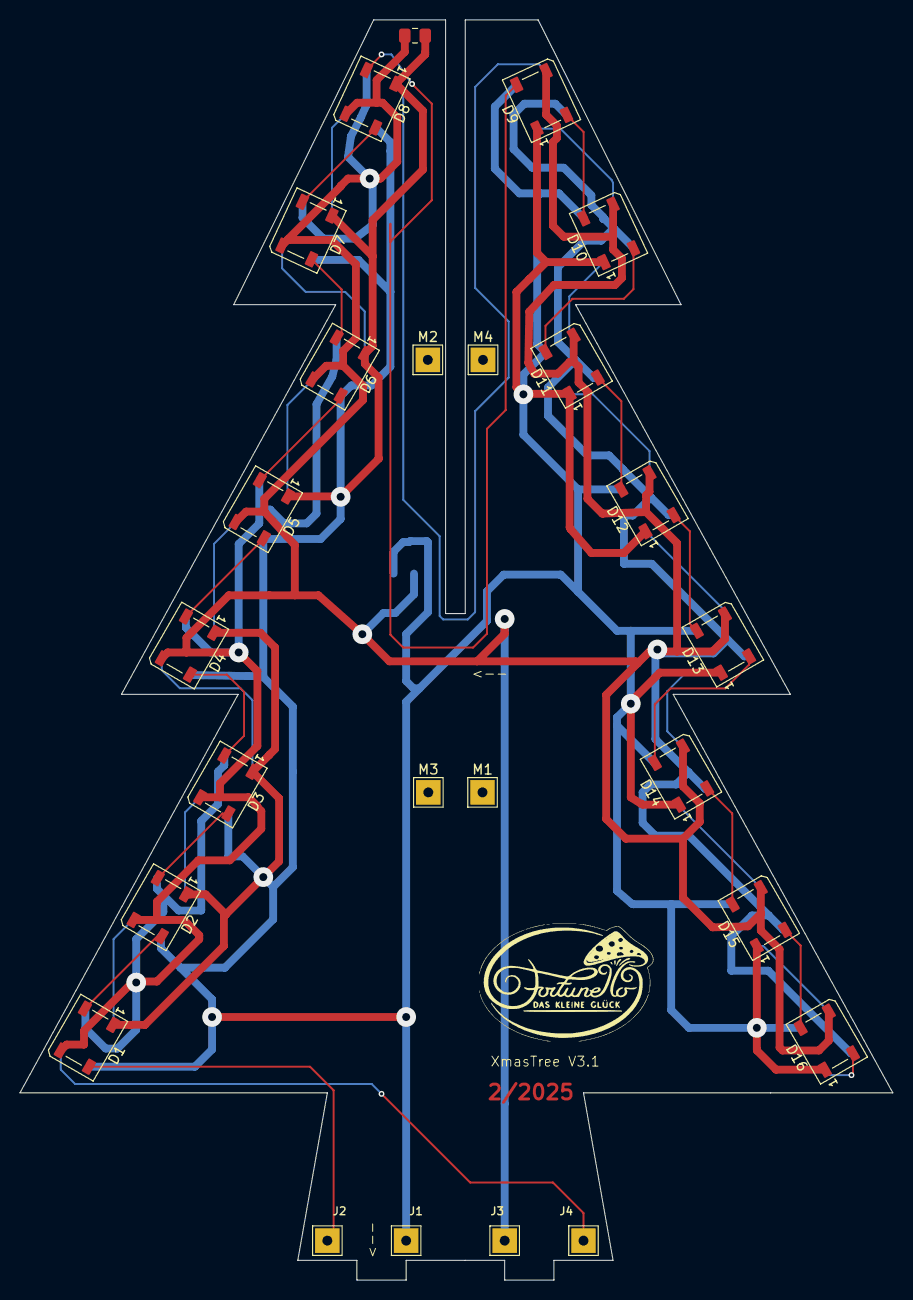
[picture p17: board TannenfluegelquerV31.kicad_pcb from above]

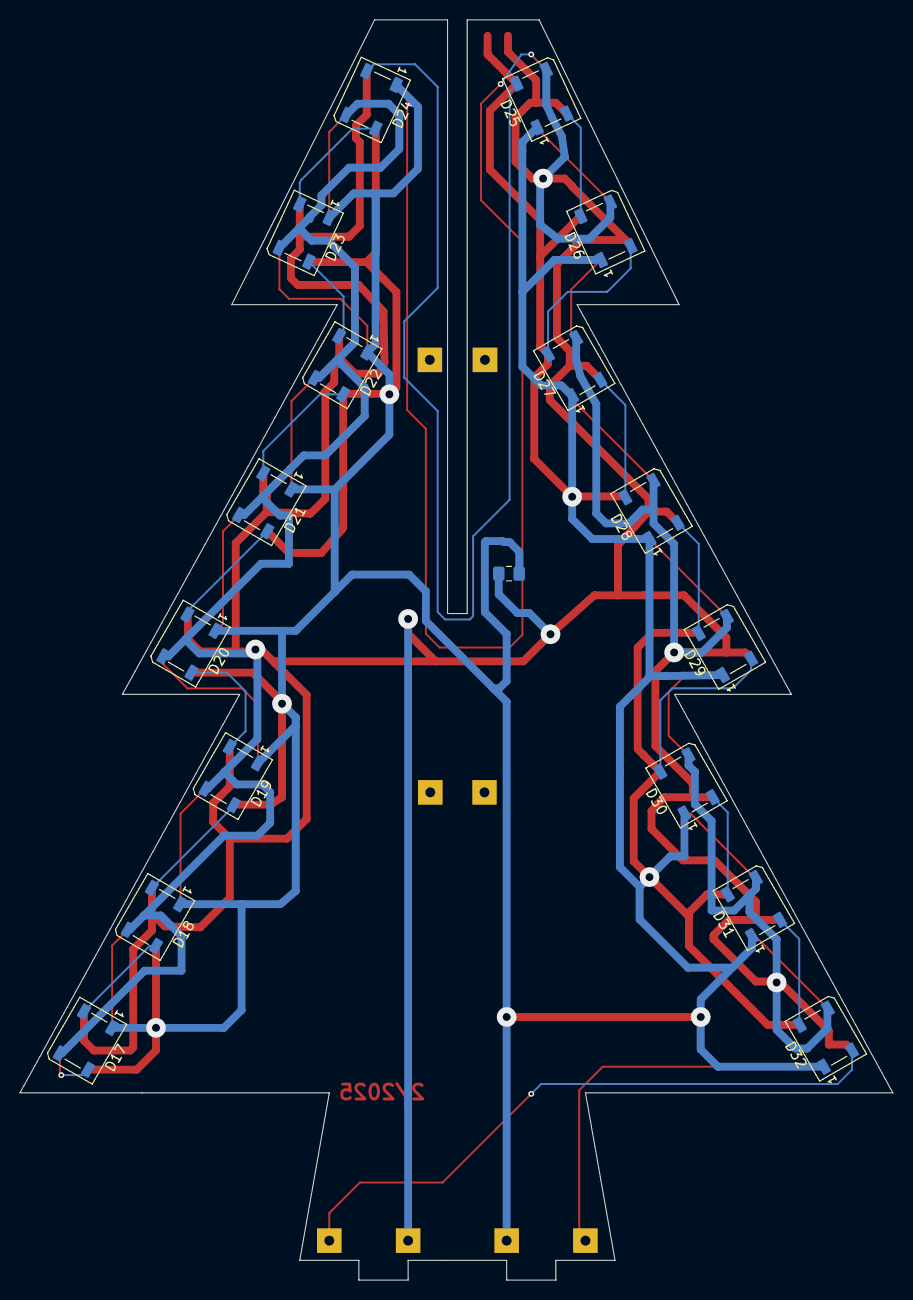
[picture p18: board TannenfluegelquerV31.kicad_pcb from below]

Board: 2 copper layers, 88.6 x 127.9 mm, 42 parts (17 on the bottom side), 35 nets.

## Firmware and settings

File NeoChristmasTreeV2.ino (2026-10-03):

/*
 * Example code for the ESP32 Tree Developer Board
 * This code is only an example of how the board can be used. In addition to controlling the Neopixels,
 * which is not particularly challenging, the example mainly illustrates the programmatic interaction
 * with the power‑management system. It also highlights the specifics of using the IR library in parallel
 * with the Neopixel LEDs, as well as the ability to learn commands from other IR remote controls.
 *
 * Several lighting patterns are displayed on the tree, and the user can switch between them either via
 * a button or an IR remote control or hardware switch. The remote can also be used to adjust brightness and to turn the
 * tree on and off.
 *
 * Special notes on power management:
 * The board distinguishes between USB power and battery power.
 *
 * BATTERY OPERATION
 * When running on battery, switching off via the button or the remote control results in a complete
 * shutdown of the power supply. For this purpose, a double‑click on the power button is triggered
 * in software via a FET. In an emergency, the power button can also be double‑clicked manually.
 * If the button is pressed only once, this is detected and the software triggers the required
 * double‑click via the FET. After shutdown, the board can only be powered on again using the power button.
 *
 * USB OPERATION
 * When powered via USB, the voltage regulator cannot be switched off. Pressing the power button or
 * turning the device off via the IR remote therefore only turns off the tree LEDs by displaying a
 * black pattern. Pressing the power button again or receiving the IR power‑on command restores the
 * previously active pattern.
 *
 * MODE SWITCHING
 * When USB power is removed, the board performs an electronic shutdown by generating a double‑click
 * via the FET.
 */


// ---- INCLUDES ----
#include <IRremote.hpp>             // infrared functions
#include "AllPattern.h"             // definition of all Patterns
#include "IRcodes.h"                // default IR-codes and constants
#include  <Adafruit_NeoPixel.h>     // for Use with WS2812-LEDsdas
#include <Preferences.h>            // for non valotile saving of IR-Codes, pattern and brightness
#include <WiFi.h>                   // only for deactivating WLAN to save power
#include "PatternEngine.h"
/* Arduino-Includes - uncomment in other IDEs
#include "serialprintf.ino"         // I like sprintf
#include "IRhandling.ino"           // learn and check IR-signals
#include "myPrefHandling.ino"       // load and save used preferences
#include "pattering.ino"            // display the patterns in their actual state on LEDs
#include "timerHandling.ino"        // sleep timer via the remote's "Timer" button
*/

const uint8_t LED_COUNT  = 66; // how much LEDs are on the tree?
const uint8_t BRIGHTNESS = 20; // initial brightness, attention: be aware of high power cunsumtion when using high brightness

// ---- Setting up PINS ----
// digital output
const uint8_t LED_PIN    = 16; // output to WS2812-LEDs
const uint8_t PWRFETPIN  = 15; // output to FET to simulate power-switch
const uint8_t STAT_LED   = 21; // output to LED for state-info
// digital input
const uint8_t IRRECPIN   = 38; // input data from IR-Data-Pin of VS1838B
const uint8_t SWLEARN    = 10; // input from learn/mode-switch
// analog input
const uint8_t USB5VSENSE = 05; // analog read of USB-voltage
const uint8_t PWRSWSENSE = 04; // analog read to check the state of power-switch
const uint8_t ROOMLIGHT  = 02; // analog read of ambient brightness

#define PWRSWSENSE_THRESHOLD 100  // analog threshold for power-switch detection

#define APHOSTNAME "ChristmasTree4"

// ---- AUTO-BRIGHTNESS via LDR (IO2: LDR to VCC, 100k to GND) ----
#define LDR_DARK          1000   // ADC value in darkness  → adjust!
#define LDR_BRIGHT        3500   // ADC value in bright light → adjust!
#define AUTO_BR_MIN           3  // LED brightness in darkness  (0–255)
#define AUTO_BR_MAX         255  // LED brightness in full light (0–255)
#define AUTO_BR_INTERVAL    500  // measurement interval in ms

// ---- GLOBAL ----
Preferences preferences;                  // stores IR codes, pattern ID and brightness
int gPatStep = 0;                         // current animation step of the selected pattern

// Pattern ID as string instead of int index
char gSelectedPatternId[32] = "offpattern"; // active pattern; "offpattern" = tree off

// Shared state flags (volatile for task-safe access)
volatile bool gNeedPatternReload = true;  // true → loop reloads the pattern from LittleFS

Adafruit_NeoPixel strip(LED_COUNT,
                        LED_PIN,
                        NEO_GRB + NEO_KHZ800);
int gBrightness = BRIGHTNESS;             // user-set maximum brightness (IR/Preferences)
unsigned long gLastLdrCheck = 0;          // timestamp of the last LDR measurement
unsigned int gIRcodes[13];               // 13 IR codes: pattern 0–7, off, on, darker, brighter, timer

// ---- Sleep timer via the remote's "Timer" button (see timerHandling.ino) ----
#define TIMER_MAX_LEVEL        8                 // levels 1..8 (30 minutes to 4 hours)
#define TIMER_STEP_MS   (30UL * 60UL * 1000UL)   // 30 minutes per level
#define TIMER_PREVIEW_MS       3000              // duration of the LED preview per button press

int  gTimerLevel         = 0;      // 0 = timer inactive, 1..8 = current level
bool gTimerPreviewActive = false;  // true during the 3s LED preview after a button press
unsigned long gTimerPreviewUntil = 0;  // millis(), until when the preview runs
unsigned long gTimerOffAt        = 0;  // millis(), when the tree should switch off automatically


/*
 * Reads the LDR at ROOMLIGHT and adjusts the strip brightness to the ambient light.
 * gBrightness (set via IR) acts as an upper limit — manual dimming stays in effect.
 */
void updateAutoBrightness() {
  unsigned long now = millis();
  if (now - gLastLdrCheck < AUTO_BR_INTERVAL) return;
  gLastLdrCheck = now;

  int raw    = analogRead(ROOMLIGHT);
  int clamped = constrain(raw, LDR_DARK, LDR_BRIGHT);
  int autoBr  = map(clamped, LDR_DARK, LDR_BRIGHT, AUTO_BR_MIN, AUTO_BR_MAX);
  autoBr      = constrain(autoBr, AUTO_BR_MIN, gBrightness);
  strip.setBrightness(autoBr);
  serialPrintf("ROOMLIGHT=%d autoBr=%d\n", raw, autoBr);
}


// little function to emulate power-off switching the voltage regulator (double-click)
void powerOff() {
    digitalWrite(PWRFETPIN, HIGH);
    delay(250);
    digitalWrite(PWRFETPIN, LOW);
    delay(300);
    digitalWrite(PWRFETPIN, HIGH);
    delay(250);
    digitalWrite(PWRFETPIN, LOW);
    delay(300); 
    Serial.println("powered off"); 
}


// ---- SETUP ----
void setup() {

  btStop();  // always turn off Bluetooth, saves power
  // WiFi is NOT disabled here — setupWiFi() in webserver.ino
  // decides based on USB5VSENSE whether to start the AP or turn WiFi off

  // setting up hardware-pins
  pinMode(IRRECPIN, INPUT);
  pinMode(STAT_LED, OUTPUT);
  pinMode(PWRFETPIN, OUTPUT);
  digitalWrite(PWRFETPIN, LOW);
  pinMode(SWLEARN, INPUT_PULLUP);

  // setup serial to use for debugging
  Serial.begin(115200);
  delay(500);
  Serial.println("Good Morning, Dave...");

  // load IR-codes, last used pattern and last brightness-value
  getPreferences();

  // setup LEDs
  strip.begin();                      // initialize NeoPixel strip object (REQUIRED)
  strip.setBrightness(gBrightness);   // set brightness before displaying
  strip.show();                       // activate LEDs
  digitalWrite(STAT_LED, LOW);        // power state-LED off

  // start IR-receiving
  IrReceiver.begin(IRRECPIN, DISABLE_LED_FEEDBACK); // activate the IR pin

  // check if learn/mode-switch is pressed on powering on -> if yes, start the procedure to learn new IR-codes
  if (!digitalRead(SWLEARN)) {
    learnIR();
  }

  // Initialize LittleFS and migrate default patterns if needed
  initFilesystem();

  // Load pattern index from LittleFS (fills gPatternIds/gPatternNames/gPatternCount)
  loadPatternIndex();

  // Start WiFi AP if USB voltage is present, otherwise WiFi off
  setupWiFi();

  // Load first pattern
  loadPatternById(gSelectedPatternId);
  gNeedPatternReload = false;
}


// ---- MAIN ----
void loop() {

  // test if an IR-command is received
  checkIR();

  // Manage sleep timer: ends the 3s LED preview, or triggers the automatic
  // shutdown once the set time has been reached
  updateTimerState();

  // During the timer preview (3s after a Timer button press), the tree strip is
  // driven by renderLevelsUpTo(); patternwork() would otherwise overwrite it immediately
  if (!gTimerPreviewActive) {
    // Reload if the webserver or IR requested a new pattern
    if (gNeedPatternReload) {
      loadPatternById(gSelectedPatternId);
      gNeedPatternReload = false;
      gPatStep = 0;
    }

    // Output the current animation step of the loaded pattern to the LEDs
    patternwork();
  } else {
    // patternwork() otherwise provides the only pacing of loop() via
    // delay(gActivePattern.wait). Without it, loop() would run unthrottled here and
    // sample PWRSWSENSE thousands instead of a few times per second — a brief ADC
    // noise spike below PWRSWSENSE_THRESHOLD could then be mistaken for a power
    // button press (timer cancel + immediate shutdown on battery power).
    delay(100);
  }

  // If the learn/mode switch is pressed: move to the next pattern and save to flash
  if (!digitalRead(SWLEARN)) {
    digitalWrite(STAT_LED, HIGH);
    delay(100);
    while (!digitalRead(SWLEARN)) {}
    digitalWrite(STAT_LED, LOW);

    // Forward through the pattern list (excluding offpattern, which is always the last element)
    int nextIdx = gPatternListIndex + 1;
    if (nextIdx >= gPatternCount - 1) nextIdx = 0;  // -1: skip offpattern
    gPatternListIndex = nextIdx;
    strncpy(gSelectedPatternId, gPatternIds[nextIdx], 31);
    gSelectedPatternId[31] = '\0';
    gNeedPatternReload = true;
    gPatStep = 0;
    writePreferences();
  }

  // Power button: toggles between offpattern and the last saved pattern
  if (analogRead(PWRSWSENSE) < PWRSWSENSE_THRESHOLD) {
    resetTimerState();  // manually turning on/off makes a running sleep timer moot
    if (strcmp(gSelectedPatternId, "offpattern") != 0) {
      strncpy(gSelectedPatternId, "offpattern", 31);
      gNeedPatternReload = true;
    } else {
      getPreferences();  // loads the last saved pattern into gSelectedPatternId
      gNeedPatternReload = true;
    }
    delay(1000);  // debounce
    serialPrintf( "USB5VSENSE %d\n", analogRead(USB5VSENSE));
  }

  // If the tree is off and USB power is missing → actual shutdown
  if ((analogRead(USB5VSENSE) < 1000) && (strcmp(gSelectedPatternId, "offpattern") == 0)) {
    powerOff();
    serialPrintf( "USB5VSENSE %d --> should power off!\n", analogRead(USB5VSENSE));
  }

  updateAutoBrightness();
}

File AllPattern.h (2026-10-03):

// ID-names for entries in colordef to be able to define patterns more readable
#define BLK  0
#define RD1  1
#define RD2  2
#define RD3  3
#define RD4  4
#define RD5  5
#define GN1  6
#define GN2  7
#define GN3  8
#define GN4  9
#define GN5 10
#define BL1 11
#define BL2 12
#define BL3 13
#define BL4 14
#define BL5 15
#define YL1 16
#define YL2 17
#define YL3 18
#define YL4 19
#define YL5 20
#define CY1 21
#define CY2 22
#define CY3 23
#define CY4 24
#define CY5 25
#define MG1 26
#define MG2 27
#define MG3 28
#define MG4 29
#define MG5 30
#define WH1 31
#define WH2 32
#define WH3 33
#define WH4 34
#define WH5 35

// Color-definitions for red, green, blue, yellow, cyan, magenta and white in five different brightness values and one black-value
int colordef [36] [3] = {
  {   0,   0,   0 },  // BLK
  {  50,   0,   0 },  // RD1
  { 100,   0,   0 },  // RD2
  { 150,   0,   0 },  // RD3
  { 200,   0,   0 },  // RD4
  { 255,   0,   0 },  // RD5
  {   0,  50,   0 },  // GN1
  {   0, 100,   0 },  // GN2
  {   0, 150,   0 },  // GN3
  {   0, 200,   0 },  // GN4
  {   0, 255,   0 },  // GN5
  {   0,   0,  50 },  // BL1
  {   0,   0, 100 },  // BL2
  {   0,   0, 150 },  // BL3
  {   0,   0, 200 },  // BL4
  {   0,   0, 255 },  // BL5
  {  50,  50,   0 },  // YL1
  { 100, 100,   0 },  // YL2
  { 150, 150,   0 },  // YL3
  { 200, 200,   0 },  // YL4
  { 255, 255,   0 },  // YL5
  {   0,  50,  50 },  // CY1
  {   0, 100, 100 },  // CY2
  {   0, 150, 150 },  // CY3
  {   0, 200, 200 },  // CY4
  {   0, 255, 255 },  // CY5
  {  50,   0,  50 },  // MG1
  { 100,   0, 100 },  // MG2
  { 150,   0, 150 },  // MG3
  { 200,   0, 200 },  // MG4
  { 255,   0, 255 },  // MG5
  {  50,  50,  50 },  // WH1
  { 100, 100, 100 },  // WH2
  { 150, 150, 150 },  // WH3
  { 200, 200, 200 },  // WH4
  { 255, 255, 255 }   // WH5
};

// ##################### PATTERN-DEFINITIONS ################################

// ============ SMOOTH RANDOM PATTERN ===================

#define LEDLENRANDOMPATTERN 10          // How much LEDs are defined with this pattern?
#define LENRANDOMPATTERN    64          // How much states are defined for this pattern
#define WAITRANDOMPATTERN   30          // Which wait-time between each step has to be used

int randompattern [LENRANDOMPATTERN] [LEDLENRANDOMPATTERN] = {

    { RD1, GN4, CY3, RD3, BL5, YL3, BL3, MG5, YL2, MG1 },
    { RD3, GN3, CY4, RD2, BL4, YL4, BL2, MG4, YL3, MG2 },
    { RD5, GN2, CY5, RD1, BL3, YL5, BL1, MG3, YL4, MG3 },
    { RD3, GN1, CY4, BLK, BL2, YL4, BLK, MG2, YL5, MG4 },
    { RD1, BLK, CY3, GN1, BL1, YL3, CY1, MG1, YL4, MG5 },
    { RD1, BL1, CY2, GN2, BLK, YL2, CY2, BLK, YL3, MG4 },
    { RD2, BL2, CY1, GN3, CY1, YL1, CY3, YL1, YL2, MG3 },
    { RD3, BL3, BLK, GN4, CY2, YL1, CY4, YL2, YL1, MG2 },
    { RD4, BL4, MG1, GN5, CY3, YL3, CY5, YL3, CY1, MG1 },
    { RD5, BL5, MG2, GN4, CY4, YL5, CY4, YL4, CY3, BLK },
    { RD4, BL4, MG3, GN3, CY5, YL3, CY3, YL5, CY5, YL1 },
    { RD3, BL3, MG4, GN2, CY4, YL1, CY2, YL4, CY3, YL2 },
    { RD2, BL2, MG5, GN1, CY3, RD1, CY1, YL3, CY1, YL3 },
    { RD1, BL1, MG4, BLK, CY2, RD2, BLK, YL2, RD1, YL4 },
    { BLK, BLK, MG3, BL1, CY1, RD3, MG1, YL1, RD2, YL5 },
    { GN1, CY1, MG2, BL2, BLK, RD4, MG2, BL1, RD3, YL4 },
    { GN2, CY2, MG1, BL3, MG1, RD5, MG3, BL3, RD4, YL3 },
    { GN3, CY3, BLK, BL4, MG2, RD4, MG4, BL5, RD5, YL2 },
    { GN4, CY4, YL1, BL5, MG3, RD3, MG5, BL3, RD4, YL1 },
    { GN5, CY5, YL2, BL4, MG4, RD2, MG4, BL1, RD3, BL1 },
    { GN4, CY4, YL3, BL3, MG5, RD1, MG3, RD1, RD2, BL3 },
    { GN3, CY3, YL4, BL2, MG4, BLK, MG2, RD2, RD1, BL5 },
    { GN2, CY2, YL5, BL1, MG3, GN1, MG1, RD3, BLK, BL3 },
    { GN1, CY1, YL4, BLK, MG2, GN2, BLK, RD4, GN1, BL1 },
    { BLK, BLK, YL3, CY1, MG1, GN3, YL1, RD5, GN2, RD1 },
    { BL1, MG1, YL2, CY2, BLK, GN4, YL2, RD4, GN3, RD2 },
    { BL2, MG2, YL1, CY3, YL1, GN5, YL3, RD3, GN4, RD3 },
    { BL3, MG3, GN1, CY4, YL2, GN4, YL4, RD2, GN5, RD4 },
    { BL4, MG4, GN3, CY5, YL3, GN3, YL5, RD1, GN4, RD5 },
    { BL5, MG5, GN5, CY4, YL4, GN2, YL4, BLK, GN3, RD4 },
    { BL4, MG4, GN3, CY3, YL5, GN1, YL3, GN1, GN2, RD3 },
    { BL3, MG3, GN1, CY2, YL4, BLK, YL2, GN2, GN1, RD2 },
    { BL2, MG2, RD1, CY1, YL3, BL1, YL1, GN3, BLK, RD1 },
    { BL1, MG1, RD2, BLK, YL2, BL2, MG1, GN4, BL1, BLK },
    { BLK, BLK, RD3, MG1, YL1, BL3, MG3, GN5, BL2, GN1 },
    { CY1, YL1, RD4, MG2, CY1, BL4, MG5, GN4, BL3, GN2 },
    { CY2, YL2, RD5, MG3, CY3, BL5, MG3, GN3, BL4, GN3 },
    { CY3, YL3, RD4, MG4, CY5, BL4, MG1, GN2, BL5, GN4 },
    { CY4, YL4, RD3, MG5, CY3, BL3, RD1, GN1, BL4, GN5 },
    { CY5, YL5, RD2, MG4, CY1, BL2, RD2, BLK, BL3, GN4 },
    { CY4, YL4, RD1, MG3, RD1, BL1, RD3, BL1, BL2, GN3 },
    { CY3, YL3, BLK, MG2, RD2, BLK, RD4, BL2, BL1, GN2 },
    { CY2, YL2, GN1, MG1, RD3, CY1, RD5, BL3, BLK, GN1 },
    { CY1, YL1, GN2, BLK, RD4, CY2, RD4, BL4, CY1, BLK },
    { BLK, MG1, GN3, YL1, RD5, RD3, BL5, YL3, CY2, BL1 },
    { MG1, MG3, GN4, YL2, RD4, RD2, BL4, YL4, CY3, BL2 },
    { MG2, MG5, GN5, YL3, RD3, RD1, BL3, YL5, CY4, BL3 },
    { MG3, MG3, GN4, YL4, RD2, BLK, BL2, YL4, CY5, BL4 },
    { MG4, MG1, GN3, YL5, RD1, GN1, BL1, YL3, CY4, BL5 },
    { MG5, RD1, GN2, YL4, BLK, GN2, BLK, YL2, CY3, BL4 },
    { MG4, RD2, GN1, YL3, GN1, GN3, CY1, YL1, CY2, BL3 },
    { MG3, RD3, BLK, YL2, GN2, GN4, CY2, BLK, CY1, BL2 },
    { MG2, RD4, BL1, YL1, GN3, GN5, CY3, BLK, BLK, BL1 },
    { MG1, RD5, BL2, BL1, GN4, GN4, CY4, BLK, MG1, BLK },
    { BLK, RD4, BL3, BL3, GN5, GN3, CY5, BLK, MG2, CY1 },
    { YL1, RD3, BL4, BL5, GN4, GN2, CY4, BLK, MG3, CY2 },
    { YL2, RD2, BL5, BL3, GN3, GN1, CY3, RD1, MG4, CY3 },
    { YL3, RD1, BL4, BL1, GN2, BLK, CY2, RD2, MG5, CY4 },
    { YL4, BLK, BL3, RD1, GN1, BL1, CY1, RD3, MG4, CY5 },
    { YL5, GN1, BL2, RD2, BLK, BL2, BLK, RD4, MG3, CY4 },
    { YL4, GN2, BL1, RD3, BL1, BL3, MG1, RD5, MG2, CY3 },
    { YL3, GN3, BLK, RD4, BL2, BL4, MG2, RD4, MG1, CY2 },
    { YL2, GN4, CY1, RD5, BL3, BL5, MG3, RD3, BLK, CY1 },
    { YL1, GN5, CY2, RD4, BL4, BL4, MG4, RD2, YL1, BLK }

};


// ============ CANDLE PATTERN ===================


#define LEDLENCDLPATTERN 66
#define LENCDLPATTERN    20
#define WAITCDLPATTERN  100
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

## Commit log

2026-10-03 Initial release: pattern engine, IR remote, WiFi pattern editor, power management
    - 66x WS2812 LEDs across a 4-wing, dual-PCB tree
    - JSON patterns stored on LittleFS, selectable via IR remote or front switch
    - Learnable IR remote (12 codes: patterns, on/off, brightness)
    - Browser-based pattern editor served over a local WiFi AP (USB power only)
    - Proper power management: full shutdown on battery via FET double-click,
    LEDs-only off on USB
2026-10-03 Add LDR auto-brightness
    Onboard light sensor (LDR on IO2) adjusts LED brightness to the ambient
    light; the brightness set via remote acts as the upper limit.
2026-10-03 Add sleep timer via remote's Timer button
    Each press raises the auto-off time by 30 minutes (up to 4 hours),
    showing the corresponding 'level' of the tree's wings as feedback for 3s.
    Pressing Timer again at the top level cancels it immediately.
    - 13th learnable IR code; debounced against repeat frames from cheap remotes
    - Learn-mode progress indicator now lights a full level across all 4 wings
    instead of a single LED, and the confirmation blink uses both tip LEDs
    - Preserves loop() pacing during the timer preview so the power-button
    sense input isn't oversampled while patternwork() is skipped
    [IRhandling.ino, NeoChristmasTreeV2.ino, myPrefHandling.ino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]
2026-10-03 Reorganize docs: PDF-only manual/system docs, add wing-board KiCad sources
    - Drop BEDIENUNGSANLEITUNG.md/.docx/.odt and SYSTEMDOKU.docx from the repo;
    the manual ships as docs/manual PDF only, SYSTEMDOKU as docs/system PDF
    only (content describes an earlier hardware revision)
    - Remove docs/superpowers/ (internal planning docs, not needed in the repo)
    - Add KiCad sources + gerbers for the two wing PCBs (Tannenfluegellaengs,
    Tannenfluegelquer) under docs/Leiterplatten/
    [TannenfluegellaengsV31-B_Cu.gbr, TannenfluegellaengsV31-B_Mask.gbr, TannenfluegellaengsV31-B_Paste.gbr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]
2026-10-03 Add main control board (TannenbasisV4) KiCad sources
    Adds the ESP32/IR/LDR/power-management control board alongside the two
    wing PCBs already under docs/Leiterplatten/.
    [TannenbasisV4-B_Cu.gbr, TannenbasisV4-B_Mask.gbr, TannenbasisV4-B_Paste.gbr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]
2026-10-03 Add front/back PCB renders for the wing boards
    Same style as docs/pcb_front.pdf and docs/pcb_back.pdf (F.Cu/B.Cu +
    Silkscreen + Edge.Cuts plotted via kicad-cli), one pair per wing board.
2026-10-03 Move control-board PCB renders into docs/Leiterplatten/TannenbasisV4/
    Same front/back render pair as the wing boards, replacing the old
    docs/pcb_front.pdf / docs/pcb_back.pdf at the docs/ root.
2026-10-03 Remove redundant docs/schematic.pdf
    Duplicate of docs/Leiterplatten/TannenbasisV4/TannenbasisV4-SCH.pdf.
2026-10-03 Add 3D-printed base housing STL files
    Two-part base housing for the tree, printable from docs/Gehäuse/.
    [XmasTree-Base3-2-end.stl, XmasTree-Base3-2-main.stl]
